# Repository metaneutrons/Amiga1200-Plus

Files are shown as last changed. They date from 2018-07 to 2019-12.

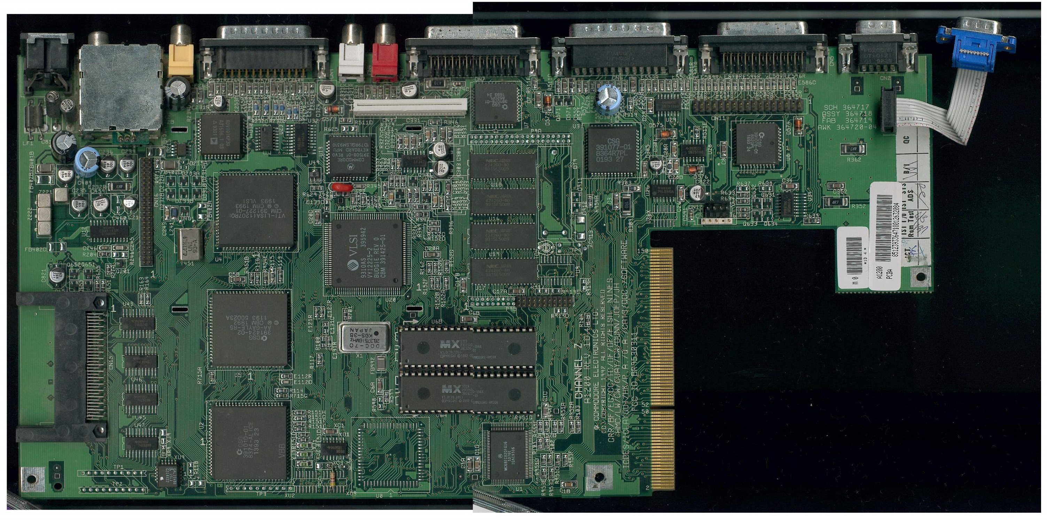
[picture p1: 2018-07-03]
a1200mb_rev1d4.jpg

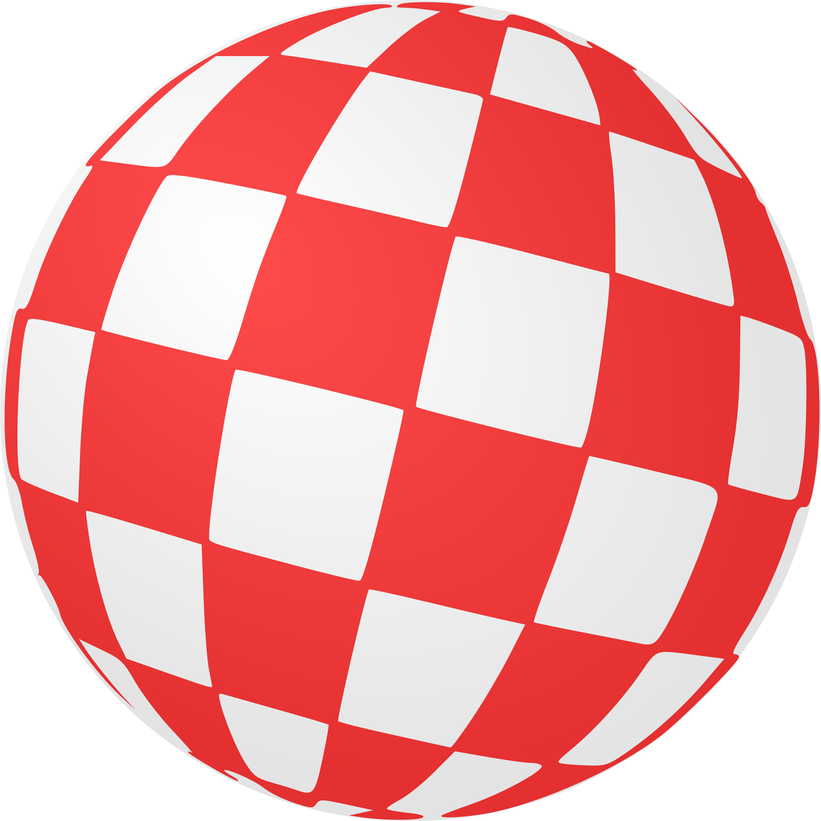
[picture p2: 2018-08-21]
Images/AmigaBall.png

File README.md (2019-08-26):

Scheme
# Amiga 1200+

## About

This project is a re-implementation of the Amiga 1200 board started from the schematics.
I made some changes and enhancements to the original schematics.

## Features

* All Original AA chips are needed and can be put into the sockets. These include Lisa, Paula, Alice and the two CIA chips.
* The CPU is removed, you need some accellerator board to run this board.
* The DRAM has been removed and the functionality has been moved to a daughterboard.
* Video output has been moved to a seperate output board. This board get all Lisa output signals and also all the typical Zorro signals. This means that an RTG card can be developed.
* The PCMCIA slot has been removed and in the free space a Compact Flash socket has been added.
* A 110V-240V AC-DC powersupply has been added, so no more power brick. This generates these voltages:
    * 5 Volts: main power rail 5 Amp capable
    * 12 Volts: 0.8 Amp capable
* two PC standard 3 Pin fan headers are added to the board.
* A non-volatile digipot has been added in the audio path, this allows you to set the stereo separation.
* Extension board connector for Mouse/Joystick/Network/FlashFloppy. (one is in development that has USB Mouse and two classic DB-9 connectors and autoswitches when fire button is pressed + ethernet)
* Replaced the keyboard controller by a modern MCU
* Dual ROM switcher
* DF0/DF1 Bootselector

## License


This project is licensed by a Creative Commons license; You are welcome (and encouraged!) to extend, re-spin and otherwise use and modify the design as allowed by the license. - see  [Creative Commons](https://creativecommons.org/licenses/by-sa/4.0/) for details

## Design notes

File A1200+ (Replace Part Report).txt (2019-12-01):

Replace Part Report
-------------------

Report Written : 6/10/2019 14:34:41
Design Path    : X:\Personal\Amiga1200Plus\A1200+.sch
Design Title   : A1200+
Created        : 26/06/2018 20:48:32
Last Saved     : 29/09/2019 12:27:12
Editing Time   : 21053 min

Replace Part:	6800pF/250V Ceramic 0805
Footprint:	<Any Footprint>

With Part:	3900pF/200V Ceramic 0805
Footprint:	<Default Footprint>

Replace matching components in the selection.

The following components were replaced:
---------------------------------------
C40
C30

                ---------------- End Of Report ----------------

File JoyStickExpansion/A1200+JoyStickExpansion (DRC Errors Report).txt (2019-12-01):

DRC Errors Report
-----------------

Report Written : 22/09/2019 14:22:56
Design Path    : X:\Personal\Amiga1200Plus\JoyStickExpansion\A1200+JoyStickExpansion.pcb
Design Title   : 
Created        : 9/06/2019 21:36:26
Last Saved     : 22/09/2019 14:22:43
Editing Time   : 2385 min

No errors found

The following rules were not checked:
    Spacing Rules:
        Testpoint
        Text
        Component
    All On Grid Rules
    Manufacturing Rules:
        Unreachable Testpoints
        Minimum Probe Points
        Split Plane Pad
        Bond Wire Length
        Wire Cross
        Wire Under Component
        Drill Backoff
        Minimum Pad Land
    Net Rules:
        Single Pin Nets
        Unfinished Track
        Track Layer
        Track Length
        Connection Length
        Connection Vias
        Pin Order
        Stub Via

All acceptance rules were checked.

No net class spacing rules defined.

No net class pair rules defined.

                ---------------- End Of Report ----------------

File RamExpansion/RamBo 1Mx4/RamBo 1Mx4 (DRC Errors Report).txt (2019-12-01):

DRC Errors Report
-----------------

Report Written : 19/09/2019 10:40:06
Design Path    : X:\Personal\Amiga1200Plus\RamExpansion\RamBo 1Mx4\RamBo 1Mx4.pcb
Design Title   : 
Created        : 8/06/2019 19:15:11
Last Saved     : 19/09/2019 10:40:02
Editing Time   : 418 min

No errors found

The following rules were not checked:
    Spacing Rules:
        Testpoint
        Text
        Component
    All On Grid Rules
    Manufacturing Rules:
        Unreachable Testpoints
        Minimum Probe Points
        Split Plane Pad
        Bond Wire Length
        Wire Cross
        Wire Under Component
        Drill Backoff
        Minimum Pad Land
    Net Rules:
        Single Pin Nets
        Unfinished Track
        Track Layer
        Track Length
        Connection Length
        Connection Vias
        Pin Order
        Stub Via

All acceptance rules were checked.

No net class spacing rules defined.

No net class pair rules defined.

                ---------------- End Of Report ----------------

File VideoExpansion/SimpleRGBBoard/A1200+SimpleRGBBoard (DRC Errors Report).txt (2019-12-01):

DRC Errors Report
-----------------

Report Written : 21/09/2019 11:47:59
Design Path    : X:\Personal\Amiga1200Plus\VideoExpansion\SimpleRGBBoard\A1200+SimpleRGBBoard.pcb
Design Title   : 
Created        : 5/06/2019 19:54:43
Last Saved     : 21/09/2019 11:47:56
Editing Time   : 632 min

No errors found

The following rules were not checked:
    Spacing Rules:
        Testpoint
        Text
        Component
    All On Grid Rules
    Manufacturing Rules:
        Unreachable Testpoints
        Minimum Probe Points
        Split Plane Pad
        Bond Wire Length
        Wire Cross
        Wire Under Component
        Drill Backoff
        Minimum Pad Land
    Net Rules:
        Single Pin Nets
        Unfinished Track
        Track Layer
        Track Length
        Connection Length
        Connection Vias
        Pin Order
        Stub Via

All acceptance rules were checked.

No net class spacing rules defined.

No net class pair rules defined.

                ---------------- End Of Report ----------------

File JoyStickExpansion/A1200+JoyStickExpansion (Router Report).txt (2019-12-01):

Router Report
-------------

Report Written : 22/09/2019 14:00:09
Design Path    : X:\Personal\Amiga1200Plus\JoyStickExpansion\A1200+JoyStickExpansion.pcb
Design Title   : 
Created        : 9/06/2019 21:36:26
Last Saved     : 22/09/2019 13:59:12
Editing Time   : 2362 min

Nets          =      173
Components    =       78
Connections   =      330
Vias          =      268
Routed Length =   2387.3 mm
Signal Layers =        4
Power Layers  =        0
Total Pins    =      597
Completion    =  100.00%
Unroutes      =        0
Routing Time  = 00:00:40

____________________________________________________________________________________________
|     |          |        |        |        |        |        |        |         |         |
|  #  |   Algo   | Shorts |DRC Errs|Failures|Unwired |  Vias  |  %Red  |  Time   |  Total  |
|_____|__________|________|________|________|________|________|________|_________|_________|
|    1| Bus      |       0|      66|       0|      21|     220|        |  0:00:00|  0:00:00|
|    2| Fanout   |       0|      67|       0|      21|     260|        |  0:00:01|  0:00:01|
|    3| Fanout   |       0|      66|       0|      21|     260|        |  0:00:00|  0:00:01|
|    4| Fanout   |       0|      66|       0|      21|     260|        |  0:00:00|  0:00:01|
|    5| Fanout   |       0|      66|       0|      21|     260|        |  0:00:01|  0:00:02|
|    6| Fanout   |       0|      66|       0|      21|     260|        |  0:00:00|  0:00:02|
|    7| Route    |       7|      66|       4|       0|     269|       0|  0:00:08|  0:00:10|
|    8| Route    |       0|      66|       5|       0|     271|       9|  0:00:03|  0:00:13|
|    9| Route    |       0|      66|       4|       0|     271|       0|  0:00:01|  0:00:14|
|   10| Route    |       0|      66|       4|       0|     269|       0|  0:00:00|  0:00:14|
|   11| Route    |       0|      66|       4|       0|     269|       0|  0:00:01|  0:00:15|
|   12| Route    |       0|      66|       4|       0|     269|       0|  0:00:00|  0:00:15|
|   13| Route    |       0|      66|       4|       0|     269|       0|  0:00:01|  0:00:16|
|   14| Route    |       0|      66|       4|       0|     269|       0|  0:00:00|  0:00:16|
|   15| Route    |       0|      66|       4|       0|     269|       0|  0:00:01|  0:00:17|
|   16| Route    |       0|      66|       4|       0|     269|       0|  0:00:00|  0:00:17|
|   17| Route    |       0|      66|       4|       0|     269|       0|  0:00:01|  0:00:18|
|   18| Route    |       0|      66|       4|       0|     269|       0|  0:00:00|  0:00:18|
|   19| Route    |       0|      66|       4|       0|     269|       0|  0:00:01|  0:00:19|
|   20| Route    |       0|      66|       4|       0|     269|       0|  0:00:00|  0:00:19|
|   21| Route    |       0|      66|       4|       0|     269|       0|  0:00:01|  0:00:20|
|   22| Route    |       0|      66|       4|       0|     269|       0|  0:00:00|  0:00:20|
|   23| Route    |       0|      66|       4|       0|     269|       0|  0:00:01|  0:00:21|
|   24| Route    |       0|      66|       4|       0|     269|       0|  0:00:00|  0:00:21|
|   25| Route    |       0|      66|       4|       0|     269|       0|  0:00:01|  0:00:22|
|   26| Route    |       0|      66|       4|       0|     269|       0|  0:00:00|  0:00:22|
|   27| Route    |       0|      66|       4|       0|     269|       0|  0:00:00|  0:00:22|
|   28| Route    |       0|      66|       4|       0|     269|       0|  0:00:00|  0:00:22|
|   29| Route    |       0|      66|       4|       0|     269|       0|  0:00:01|  0:00:23|
|   30| Route    |       0|      66|       4|       0|     269|       0|  0:00:00|  0:00:23|
|   31| Route    |       0|      66|       4|       0|     269|       0|  0:00:01|  0:00:24|
|   32| Filter   |       0|      66|       4|       0|     269|       0|  0:00:00|  0:00:24|
|   33| Filter   |       0|      66|       4|       0|     269|       0|  0:00:01|  0:00:25|
|   34| Filter   |       0|      66|       4|       0|     269|       0|  0:00:00|  0:00:25|
|   35| Filter   |       0|      66|       4|       0|     269|       0|  0:00:01|  0:00:26|
|   36| Filter   |       0|      66|       4|       0|     269|       0|  0:00:00|  0:00:26|
|   37| Clean    |       0|      66|      32|       0|     270|        |  0:00:03|  0:00:29|
|   38| Clean    |       0|      66|      31|       0|     268|        |  0:00:03|  0:00:32|
|   39| Clean    |       0|      66|      32|       0|     268|        |  0:00:02|  0:00:34|
|   40| Clean    |       0|      66|      31|       0|     268|        |  0:00:03|  0:00:37|
|   40| Recorner |       0|      66|       0|       0|     268|        |  0:00:01|  0:00:38|
|_____|__________|________|________|________|________|________|________|_________|_________|

                ---------------- End Of Report ----------------

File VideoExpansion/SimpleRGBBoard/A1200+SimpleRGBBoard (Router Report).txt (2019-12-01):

Router Report
-------------

Report Written : 19/09/2019 13:59:25
Design Path    : X:\Personal\Amiga1200Plus\VideoExpansion\SimpleRGBBoard\A1200+SimpleRGBBoard.pcb
Design Title   : 
Created        : 5/06/2019 19:54:43
Last Saved     : 19/09/2019 13:58:39
Editing Time   : 602 min

Nets          =      135
Components    =       35
Connections   =      142
Vias          =      133
Routed Length =   2826.1 mm
Signal Layers =        4
Power Layers  =        0
Total Pins    =      297
Completion    =  100.00%
Unroutes      =        0
Routing Time  = 00:00:24

____________________________________________________________________________________________
|     |          |        |        |        |        |        |        |         |         |
|  #  |   Algo   | Shorts |DRC Errs|Failures|Unwired |  Vias  |  %Red  |  Time   |  Total  |
|_____|__________|________|________|________|________|________|________|_________|_________|
|    1| Bus      |       0|       0|       0|      46|      70|        |  0:00:00|  0:00:00|
|    2| Fanout   |       0|       7|       2|      46|     149|        |  0:00:01|  0:00:01|
|    3| Fanout   |       1|       1|       2|      46|     149|        |  0:00:00|  0:00:01|
|    4| Fanout   |       1|       1|       2|      46|     149|        |  0:00:00|  0:00:01|
|    5| Fanout   |       1|       0|       2|      46|     149|        |  0:00:01|  0:00:02|
|    6| Fanout   |       0|       0|       3|      46|     148|        |  0:00:00|  0:00:02|
|    7| Route    |      47|      15|       0|       0|     127|       0|  0:00:01|  0:00:03|
|    8| Route    |      29|      17|       0|       0|     130|      25|  0:00:02|  0:00:05|
|    9| Route    |      18|       1|       0|       0|     124|      58|  0:00:01|  0:00:06|
|   10| Route    |       4|       6|       0|       0|     130|      47|  0:00:01|  0:00:07|
|   11| Route    |       0|       2|       0|       0|     136|      80|  0:00:01|  0:00:08|
|   12| Route    |       0|       8|       3|       0|     136|       0|  0:00:01|  0:00:09|
|   13| Route    |       2|      15|       1|       0|     136|       0|  0:00:01|  0:00:10|
|   14| Route    |       2|      15|       4|       0|     136|       0|  0:00:01|  0:00:11|
|   15| Route    |       2|       8|       1|       0|     136|      41|  0:00:00|  0:00:11|
|   16| Route    |       1|       2|       5|       0|     136|      70|  0:00:02|  0:00:13|
|   17| Route    |       0|       7|       1|       0|     136|       0|  0:00:01|  0:00:14|
|   18| Route    |       0|       8|       4|       0|     136|       0|  0:00:01|  0:00:15|
|   19| Route    |       1|       0|       0|       0|     136|      87|  0:00:00|  0:00:15|
|   20| Route    |       0|       0|       3|       0|     138|     100|  0:00:01|  0:00:16|
|   21| Filter   |       0|       0|       0|       0|     138|       0|  0:00:00|  0:00:16|
|   22| Clean    |       0|       0|      31|       0|     135|        |  0:00:02|  0:00:18|
|   23| Clean    |       0|       0|      31|       0|     133|        |  0:00:02|  0:00:20|
|   24| Clean    |       0|       0|      32|       0|     133|        |  0:00:02|  0:00:22|
|   25| Clean    |       0|       0|      31|       0|     133|        |  0:00:02|  0:00:24|
|   25| Recorner |       0|       0|       0|       0|     133|        |  0:00:00|  0:00:24|
|_____|__________|________|________|________|________|________|________|_________|_________|

                ---------------- End Of Report ----------------

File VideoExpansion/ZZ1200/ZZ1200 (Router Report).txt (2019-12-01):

Router Report
-------------

Report Written : 16/08/2019 20:23:38
Design Path    : \\Mac\repos\Personal\Amiga1200Plus\VideoExpansion\ZZ1200\ZZ1200.pcb
Design Title   : 
Created        : 5/06/2019 19:54:43
Last Saved     : 16/08/2019 20:23:16
Editing Time   : 688 min

Nets          =      130
Components    =       10
Connections   =       62
Vias          =       51
Routed Length =    924.9 mm
Signal Layers =        4
Power Layers  =        0
Total Pins    =      460
Completion    =  100.00%
Unroutes      =        0
Routing Time  = 00:00:06

____________________________________________________________________________________________
|     |          |        |        |        |        |        |        |         |         |
|  #  |   Algo   | Shorts |DRC Errs|Failures|Unwired |  Vias  |  %Red  |  Time   |  Total  |
|_____|__________|________|________|________|________|________|________|_________|_________|
|    1| Bus      |       0|       0|       0|      45|      17|        |  0:00:00|  0:00:00|
|    2| Fanout   |       0|       1|      23|      45|      60|        |  0:00:00|  0:00:00|
|    3| Fanout   |       0|       0|      23|      45|      60|        |  0:00:01|  0:00:01|
|    4| Fanout   |       0|       0|      23|      45|      60|        |  0:00:00|  0:00:01|
|    5| Fanout   |       0|       0|      23|      45|      60|        |  0:00:00|  0:00:01|
|    6| Fanout   |       0|       0|      23|      45|      60|        |  0:00:00|  0:00:01|
|    7| Route    |      10|       0|       0|       0|      53|       0|  0:00:01|  0:00:02|
|    8| Route    |       5|       0|       4|       0|      55|      50|  0:00:00|  0:00:02|
|    9| Route    |       0|       0|       0|       0|      57|     100|  0:00:01|  0:00:03|
|   10| Filter   |       0|       0|       0|       0|      57|       0|  0:00:00|  0:00:03|
|   11| Clean    |       0|       0|      12|       0|      51|        |  0:00:01|  0:00:04|
|   12| Clean    |       0|       0|      12|       0|      51|        |  0:00:00|  0:00:04|
|   13| Clean    |       0|       0|      12|       0|      51|        |  0:00:01|  0:00:05|
|   14| Clean    |       0|       0|      12|       0|      51|        |  0:00:01|  0:00:06|
|   14| Recorner |       0|       0|       0|       0|      51|        |  0:00:00|  0:00:06|
|_____|__________|________|________|________|________|________|________|_________|_________|

                ---------------- End Of Report ----------------

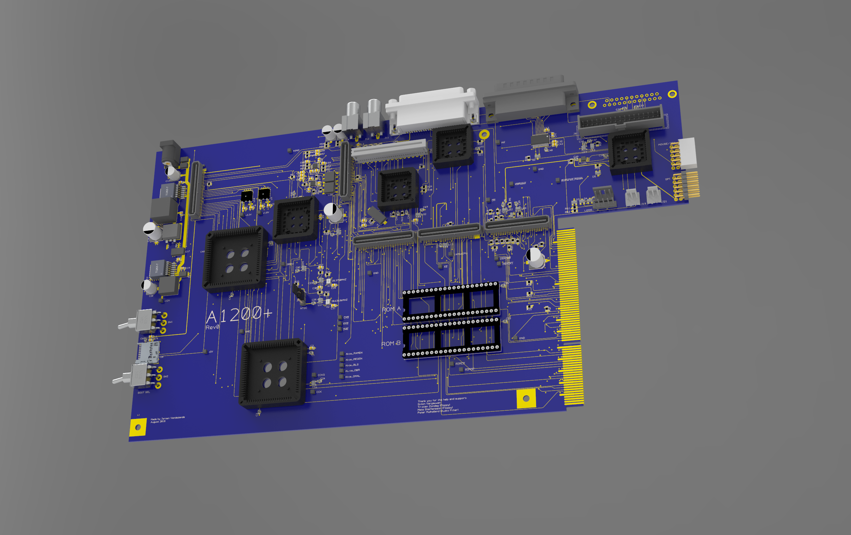
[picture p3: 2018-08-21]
Images/A1200+Render.png

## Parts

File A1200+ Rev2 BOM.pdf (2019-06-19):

### A1200+ (BOM Csv)

Count Count | Name | Value | Desc | Mfr | Part Number | Supplier | SPN | Footprint
14 | C[1-3],C5,C7,C[10-11],C26,C32,C36,C49,C58,C[60-61] | 100 nF | 3 Pin Capacitor | Murata | NFM21PC104R1E3D | | FN 1686518 | NFM21
15 | C4,C20,C[22-23],C[27-28],C33,C[37-39],C[44-47],C57 | 100nF/50V | 100nF/50V Ceramic Capacitor 0805 | MURATA | GCM21BR72A104KA37L | | FN 2470440 | 805
3 | C6,C52,C55 | 220µF/35V | Capacitor Alu Elec 220µF/35V | Panasonic | EEEFK1V221P | | FN 9695877 | Panasonic Cap Size F
1 | C8 | 1µF/50V | 1µF/50V Ceramic Capacitor 0805 | Murata | GRM21BR71H105KA12L | | FN 1735541RL | C0805
3 | C9,C16,C29 | 10µF/16V | 10µF/16V Ceramic Capacitor 0805 | Murata | GRM219R61C106KA73D | | FN 1845747 | C0805
3 | C12,C[34-35] | 220nF/50V | 220nF/50V Ceramic Capacitor 0805 | Murata | GRM21BR71H224KA01L | | FN 8820139RL | C0805
4 | C13,C17,C30,C40 | 6800pF/250V | Ceramic Capacitor 0805 | Kemet | C0805X682JAGACAUTO | Farnell | 2471761 | 805
3 | C14,C21,C50 | 100µF/35V | 100µF 35V Capacitor Hybrid Polymer | Panasonic | EEHZK1V101XP | Mouser | 667-EEH-ZK1V101XP | Panasonic Cap Size D8
2 | C15,C31 | 3900pF/200V | Ceramic Capacitor 0805 | Kemet | C0805C392J2GACAUTO | Farnell | 2426890 | 805
4 | C[18-19],C[24-25] | 100nF/50V | 100nF/50V Ceramic Capacitor 0805 | AVX | 08055C104KAZ2A | | FN 7569564 | C0805
6 | C41,C48,C51,C[53-54],C56 | 100nF | 3 Pin Capacitor | Murata | NFM21PC104R1E3D | | FN 1686518 | NFM21
2 | C[42-43] | 22pF/100V | 22pF/100V Ceramic Capacitor 0805 | AVX | 08051A220JAT2A | | FN 317500 | 805
1 | C59 | 470nF/25V | 470nF/25V Ceramic Capacitor 0805 | Kemet | C0805C474J3RACAUTO | | FN 2478263 | 805
1 | D1 | 30V / 200mA | Small Signal Schottky Diode | ON SEMICONDUCTOR | BAT54 | | FN 1467516 | SOT-23
1 | F1 | | 10A/250VAC Cartridge 5x20 Fuse Holder | WURTH ELEKTRONIK | 696105003002 | | FN 2471679 | 696105003002
1 | I1 | 10 mA | Constant Current Regulator | ON Semiconductor | NSI50010YT1GOSCT-ND | | | SOD-123
2 | J[1-2] | | RCA Connector PCB Black | CUI | RCJ-041 | Mouser | 490-RCJ-041 | RCJ-04x
1 | J3 | | DB-25 Female Right Angle | MultiComp | 8LCM025S-304B-XX | Farnell | 1099296 | DB25-FEMALE-RA
1 | J4 | | D-Sub Standard Connectors 25P MALE RIGHT ANGLE | NorComp | 182-025-113R531 | | MS 636-182-025-113R531 | DB25-MALE-RA
1 | J5 | | DB-23 Female Right Angle | | | | | DB23-FEMALE-RA
1 | J6 | | AC Power Entry Module | Qualtek | 770W-X2/10 | Mouser | 562-770W-X2/10 | 770W-X2/10
1 | J7 | | Box Header 34 Pins 2.54mm pitch | Harting | 09 18 534 7324 | Farnell | 1096992 | BOX-2x14
1 | J8 | | 31 Pin FPC connector 1.25mm Pitch | Molex | 39-53-2315 | Mouser | 538-39-53-2315 | 39-53-2315
2 | J9,J13 | | Board to Board & Mezzanine Connectors 40P 1.27 SMC Male R/A SMT Type | HARWIN | M55-7104042R | | 855-M55-7104042R | M55-7104042R
3 | J[10-12] | | FH-Board To Board Connector | TE Connectivity | 5146897-1 | Mouser | 571-5146897-1 | Free Height (FH) Plug 64
2 | J[14-15] | | Floppy Power Connector | TE CONNECTIVITY | 171825-4 | Farnell | 1654622 | 171825-4
2 | J[16-17] | | Wire-To-Board Connector, 2.54 mm, 3 Contacts, Header | Molex | 22-23-2031 | Farnell | 1462950 | FanHeader
1 | J18 | | 5 Pin SIL | AMP - TE CONNECTIVITY | 825433-5 | Farnell | 1187826 | 825433-5
1 | J19 | | Header Through Hole 22 position 2.00mm | | 57102-F08-11ULF | Digi-Key | 609-5095-ND | Header-22-2mm-TH
1 | J20 | | Compact Flash Socket | TE Connectivity | 1-1734451-1 | | | CompactFlashSocket
1 | J21 | | Header Through Hole 22 position 2.00mm | | 57102-F08-11ULF | Digi-Key | 609-5095-ND | Header-44-2mm-TH
1 | J22 | | Amiga 1200 Edge Connector | | | | | EdgeConnector_150_1.27mm
3 | JP[1-3] | | 3 Pin Jumper | | | | | Jumper_3_2.54
1 | L1 | 0.95 µH | chip ferrite bead | TE CONNECTIVITY | BMB2A0600BN3 | | FN 2329425 | 805
1 | PSU1 | 5V 30W | AC to DC power supply | Mean Well | IRM-30-5 | | 2815513 | IRM-30
2 | Q[1-2] | | MOSFET, N Channel, 2.7A, 60V | International Rectifier | IRLML0060TRPBF | | FN 1783927 | SOT-23
1 | Q3 | 7.1A / 12V | MOSFET Transistor, P Channel | Vishay | SI2333CDS-T1-GE3 | | FN 1779259 | SOT-23
3 | Q[4-6] | 60V 1.6A | MOSFET Transistor, P Channel | Vishay | SI2309CDS-T1-GE3 | | FN 1779264 | SOT-23
16 | R[1-3],R10,R17,R[21-22],R24,R30,R32,R[36-37],R40,R47,R63,R82 | 10K | Resistor Thick Film 0.1W 1% | | | | | R0805
11 | R4,R23,R29,R33,R35,R38,R55,R60,R64,R73,R85 | 1K | Resistor Thick Film 0.1W 1% | | | | | R0805
26 | R[5-9],R[11-16],R18,R[26-27],R[44-45],R48,R57,R62,R72,R[74-78],R81 | 4K7 | Resistor Thick Film 0.1W 1% | | | | | R0805
2 | R19,R25 | 360R | Resistor Thick Film 0.1W 1% | | | | | R0805
1

Count | Name | Value | Desc | Mfr | Part Number | Supplier | SPN | Footprint
1 | R20 | 10 | Resistor Thick Film 0.1W 1% | | | | | R0805
1 | R28 | 100 | Resistor Thick Film 0.1W 1% | | | | | R0805
5 | R31,R51,R54,R56,R59 | 68R | Resistor Thick Film 0.1W 1% | | | | | R0805
4 | R34,R39,R[42-43] | 330R | Resistor Thick Film 0.1W 1% | | | | | R0805
12 | R41,R[52-53],R[65-71],R[79-80] | 470 | Resistor Thick Film 0.1W 1% | | | | | R0805
1 | R46 | 1M | Resistor Thick Film 0.1W 1% | | | | | R0805
2 | R[49-50] | 200R | Resistor Thick Film 0.1W 1% | | | | | R0805
2 | R58,R61 | 470R | Resistor Thick Film 0.1W 1% | | | | | R0805
1 | R83 | 10R | Resistor Thick Film 0.1W 1% | | | | | R0805
4 | R84,R[88-89],R91 | 27R | Resistor Thick Film 0.1W 1% | | | | | R0805
3 | R[86-87],R90 | 100R | Resistor Thick Film 0.1W 1% | | | | | R0805
1 | SW1 | | Toggle Switch SPDT | Multicomp | 1MS1T2B4M7RE | Farnell | 9473297 | ToggleSwitchPCB_Vertical
7 | TP[1-7] | | Test Point | MultiComp | TEST-1(BK) | Farnell | 1702000 | TestPoint
3 | U[1-2],U14 | | Dual JFET-input Operational Amplifier | Texas Instruments | OPA1642AIDGKT | Farnell | 2323354 | MSOP8_MC
1 | U3 | | Schmitt-Trigger Inverter | ON SEMICONDUCTOR | M74VHC1GT14DTT1G | Farnell | 2534358 | SOT-23-5
6 | U[4-5],U18,U22,U25,U27 | | Single 2-input Positive-AND Gate | Texas Instruments | SN74LVC1G08DBVT | | FN 1236324 | SOT-23-5
1 | U6 | | Dual Non Volatile Digi-Pot | Analog Devices | AD5142ABRUZ10 | | 584-AD5142ABRUZ10 | TSSOP-20-B6.3-P0.65
2 | U7,U12 | | Amiga 8520 CIA | 3M | 8444-11B1-RK-TP | Farnell | 1183029 | PLCC-44
2 | U8,U10 | | Photo FET Optocoupler | On Semiconductor | H11F1SM | Farnell | 2825064 | H11F1SM
1 | U9 | | RS-232 Transceiver | Texas Instruments | SN65C3243DBR | Farnell | 2496635 | SSOP-28-P0.65-B5.3
1 | U11 | | Amiga Audio Chip | 3M | 8452-11B1-RK-TP | Farnell | 2673908 | PLCC-52
1 | U13 | | Amiga 1200 Keyboard Controller | 3M | 8444-11B1-RK-TP | Farnell | 1183029 | PLCC-44
1 | U15 | 4.0V | Power-On Reset | Texas Instruments | LP3470M5-4.00/NOPB | Farnell | 2492283 | SOT-23-5
1 | U16 | | Amiga 1200 GAL | | | | | PLCC-20-5X5-P50
1 | U17 | | Amiga Graphics Controller | 3M | 8484-11B1-RK-TP | Farnell | 1183033 | PLCC-84
1 | U19 | | Amiga 1200 Memory Controller | | | | | QFT-128_0.8
1 | U20 | | Amiga 1200 Gayle Chip | | | | | PLCC-84
2 | U21,U24 | | a 62408 rom in a DIL socket | Mill-Max Manufacturing Corp. 117-43-642-41-005000 | | Digi-Key | ED90229-ND | DIP Socket 42
1 | U23 | 12V | DC-DC Convertor 12V 10W | Meanwell | SKM10E-12 | Digikey | 1866-4632-ND | SKM10E
1 | U26 | | Amiga DMA Controller | 3M | 8484-11B1-RK-TP | Farnell | 1183033 | PLCC-84
1 | X1 | 3MHZ | Crystal HC49 SMD | Abracon LLC | ABLS-LR-3.000MHZ-T | Digi-Key | 535-10158-1-ND | HC49
1 | X2 | | | | | | | OscSocket

2

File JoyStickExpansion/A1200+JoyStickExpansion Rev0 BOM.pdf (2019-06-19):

### A1200+JoyStickExpansion (BOM Csv)

Count | Name | Value | Desc | Mfr | Part Number | Supplier | SPN | Footprint
4 | C[1-2],C28,C31 | 100nF/50V | 100nF/50V Ceramic Capacitor 0805 | AVX | 08055C104KAZ2A | | FN 7569564 | C0805
20 | C3,C[6-14],C[18-23],C[25-27],C29 | 100 nF | 3 Pin Capacitor | Murata | NFM21PC104R1E3D | | FN 1686518 | NFM21
3 | C[4-5],C24 | 10µF/16V | 10µF/16V Ceramic Capacitor 0805 | Murata | GRM219R61C106KA73D | | FN 1845747 | C0805
3 | C[15-17] | 4.7µF/100V | 4.7µF/100V Ceramic Capacitor 0805 | AVX | 12061Z475KAT2A | | FN 2310265 | C1206
1 | C30 | 1µF/50V | 1µF/50V Ceramic Capacitor 0805 | Murata | GRM21BR71H105KA12L | | FN 1735541RL | C0805
3 | D[1-3] | | Green Red 0805 | KINGBRIGHT | KP-2012MGC | | 8529906 | 0805LED
3 | I[1-3] | 10 mA | Constant Current Regulator | ON Semiconductor | NSI50010YT1GOSCT-ND | | | SOD-123
2 | J[1-2] | | Board to Board & Mezzanine Connectors 40P 1.27 SMC Female R/A SMT Type | HARWIN | M55-6104042R | | 855-M55-6104042R | M55-6104042R
1 | J3 | | 4 Pin Connector | JST | B4B-PH-SM4-TB(LF)(SN) | | FN 9491929 | PH4
2 | J[4-5] | | DE-09 Male Right Angle Connector | NorComp | 682-009-113R531 | Mouser | 636-682-009-113R531 | DE-09 Male Right Angle
1 | J6 | | 10/100BaseT RJ45 LAN Connector with integrated transformer | WURTH ELEKTRONIK | 74990111217 | | FN 2356118 | 74990111217
1 | J7 | | USB Connector Type A | WURTH ELEKTRONIK | 61400416021 | Farnell | 1642033 | USB Type A
1 | J8 | | Programming header for AVR MCUs | | | | | TC2030
1 | J9 | | 8 Pin SIL | AMP - TE CONNECTIVITY | 825433-8 | Farnell | 1187828 | SIL-8-2.54
2 | L[1-2] | 0.95 µH | chip ferrite bead | TE CONNECTIVITY | BMB2A0600BN3 | | FN 2329425 | 805
1 | Q1 | 30V, 5A | MOSFET, N Channel, 5A, 30V | Infineon | IRLML6344TRPBF | Farnell | 1857299 | SOT-23
3 | R[1-2],R7 | 4K7 | Resistor Thick Film 0.1W 1% | | | | | R0805
4 | R[3-6] | 49R9 | Resistor Thick Film 0.1W 1% | | | | | R0805
1 | R8 | 3K01 | Resistor Thick Film 0.1W 1% | | | | | R0805
2 | R[9-10] | 220R | Resistor Thick Film 0.1W 1% | | | | | R0805
2 | R[11-12] | 22R | Resistor Thick Film 0.1W 1% | | | | | R0805
1 | R13 | 10K | Resistor Thick Film 0.1W 1% | | | | | R0805
1 | R14 | 47R | Resistor Thick Film 0.1W 1% | | | | | R0805
1 | SW1 | | Toggle Switch SPDT | Multicomp | 1MS1T2B4M7RE | Farnell | 9473297 | ToggleSwitchPCB_Vertical
1 | U1 | | I2C Controller for parallel bus | NXP | PCF8584T/2,512 | | 2400586 | SOIC-20W
1 | U2 | 3.3V 250 mA | LDO Linear Voltage Regulator | Microchip | MCP1702T-3302E/CB | | FN 1331490 | SOT-23A
1 | U3 | | Ethernet Controller 100 Mbps | Microchip | KSZ8851-16MLL | Farnell | 2991829 | TQFP-48-0.5
2 | U[4-5] | | Single OR Gate | Texas Instruments | SN74LVC1G32DBVR | | FN 1287525 | SOT-23-5
3 | U[6-8] | | 8-bit dual supply Translating Transceiver with 3-state outputs | Nexperia | 74LVC8T245PW,118 | Farnell | 2444917 | TSSOP-24
1 | U9 | | 8-bit Atmel Microcontroller with USB | Microchip | AT90USB1287-AU | Farnell | 1748496 | TQFP-64
1 | U10 | | REGISTER | Nexperia | 74HC166D-Q100J | Farnell | 2777725 | SOIC16
1 | X1 | 25 MHZ | Crystal Oscillator | Epson | X1G0041710033 SG-210STF 25 MHZ L | | FN 2405724 | EPSON SG210
1 | X2 | 16 MHZ | Crystal Oscillator | Epson | 1G0041710027 SG-210STF 16 MHZ L | Farnell | 2405718 | EPSON SG210

1

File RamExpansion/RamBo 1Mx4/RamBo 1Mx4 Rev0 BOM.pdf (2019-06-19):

### RamBo 1Mx4 (BOM Csv)

Count | Name | Value | Desc | Mfr | Part Number | Supplier | SPN | Footprint
8 | C[1-8] | 100nF | 3 Pin Capacitor | Murata | NFM21PC104R1E3D | | FN 1686518 | NFM21
1 | C9 | 10µF/16V | 10µF/16V Ceramic Capacitor 0805 | Murata | GRM219R61C106KA73D | | FN 1845747 | C0805
1 | J1 | | FH-Board To Board Connector Receptacle | TE Connectivity | 5120523-1 | Mouser | 571-5120523-1 | Free Height (FH) Receptacle 64
1 | R1 | 470R | Resistor Thick Film 0.1W 1% | | | | | R0805
8 | U[1-8] | | CMOS DRAM 1Mx4 | | | | | SOJ20_RAM

1

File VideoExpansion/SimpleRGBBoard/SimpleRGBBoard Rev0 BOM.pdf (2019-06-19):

### A1200+SimpleRGBBoard (BOM Csv)

Count | Name | Value | Desc | Mfr | Part Number | Supplier | SPN | Footprint
4 | C1,C5,C[8-9] | 100nF/50V | 100nF/50V Ceramic Capacitor 0805 | MURATA | GCM21BR72A104KA37L | | FN 2470440 | 805
2 | C2,C6 | 10µF/16V | 10µF/16V Ceramic Capacitor 0805 | Murata | GRM219R61C106KA73D | | FN 1845747 | C0805
3 | C[3-4],C7 | 100nF | 3 Pin Capacitor | Murata | NFM21PC104R1E3D | | FN 1686518 | NFM21
3 | C[10-11],C14 | 10nF/50V | 10nF/50V Ceramic Capacitor 0805 | AVX | 08055C103KAT2A | | FN 499225 | 805
1 | C12 | 1µF/50V | 1µF/50V Ceramic Capacitor 0805 | Murata | GRM21BR71H105KA12L | | FN 1735541RL | C0805
1 | C13 | 100nF/50V | 100nF/50V Ceramic Capacitor 0805 | AVX | 08055C104KAZ2A | | FN 7569564 | C0805
2 | J[1-2] | | FH-Board To Board Connector Receptacle | TE Connectivity | 5120523-1 | Mouser | 571-5120523-1 | Free Height (FH) Receptacle 64
1 | J3 | | D Sub Connector, Right Angle, HD26, 26 Contacts, Plug, Through Hole, DA, Steel Body | Harting | 9562627813 | Farnell | 2752096 | DB-26 RA Male
1 | L1 | 0.95 µH | chip ferrite bead | TE CONNECTIVITY | BMB2A0600BN3 | | FN 2329425 | 805
5 | R[1-2],R[4-6] | 75 | Resistor Thick Film 0.1W 1% | | | | | R0805
1 | R3 | 360 | Resistor Thick Film 0.1W 1% | | | | | R0805
1 | R7 | 68 | Resistor Thick Film 0.1W 1% | | | | | R0805
1 | R8 | 1K | Resistor Thick Film 0.1W 1% | | | | | R0805
1 | R9 | 530R | Resistor Thick Film 0.1W 1% | | | | | R0805
1 | U1 | | Triple 8-Bit High Speed Video DAC | Analog Devices | ADV7125JSTZ240 | Farnell | 1438733 | TQFP-48-0.5
1 | U2 | | 8-bit dual supply Translating Transceiver with 3-state outputs | Nexperia | 74LVC8T245PW,118 | Farnell | 2444917 | TSSOP-24
1 | U3 | 1.235V | Voltage reference | Texas Instruments | LM385M3-1.2 | Farnell | 9778152 | SOT-23

1

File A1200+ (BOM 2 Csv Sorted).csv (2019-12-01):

Name | Value | Desc | Mfr | Part Number | Footprint
C9 | 1µF/50V | 1µF/50V Ceramic Capacitor 0805 | Murata | GRM21BR71H105KA12L | C0805
C63 | 1µF/50V | 1µF/50V Ceramic Capacitor 0805 | Murata | GRM21BR71H105KA12L | C0805
C64 | 1µF/50V | 1µF/50V Ceramic Capacitor 0805 | Murata | GRM21BR71H105KA12L | C0805
C1 | 10µF/16V | 10µF/16V Ceramic Capacitor 0805 | Murata | GRM219R61C106KA73D | C0805
C8 | 10µF/16V | 10µF/16V Ceramic Capacitor 0805 | Murata | GRM219R61C106KA73D | C0805
C16 | 10µF/16V | 10µF/16V Ceramic Capacitor 0805 | Murata | GRM219R61C106KA73D | C0805
C43 | 10µF/16V | 10µF/16V Ceramic Capacitor 0805 | Murata | GRM219R61C106KA73D | C0805
C49 | 10µF/16V | 10µF/16V Ceramic Capacitor 0805 | Murata | GRM219R61C106KA73D | C0805
C6 | 10nF/50V | 10nF/50V Ceramic Capacitor 0805 | AVX | 08055C103KAT2A | 0805
C14 | 100µF/35V | 100µF 35V Capacitor Hybrid Polymer | Panasonic | EEHZK1V101XP | Panasonic Cap Size D8
C21 | 100µF/35V | 100µF 35V Capacitor Hybrid Polymer | Panasonic | EEHZK1V101XP | Panasonic Cap Size D8
C5 | 100 nF | 3 Pin Capacitor | Murata | NFM21PC104R1E3D | NFM21
C7 | 100 nF | 3 Pin Capacitor | Murata | NFM21PC104R1E3D | NFM21
C10 | 100 nF | 3 Pin Capacitor | Murata | NFM21PC104R1E3D | NFM21
C26 | 100 nF | 3 Pin Capacitor | Murata | NFM21PC104R1E3D | NFM21
C27 | 100 nF | 3 Pin Capacitor | Murata | NFM21PC104R1E3D | NFM21
C28 | 100 nF | 3 Pin Capacitor | Murata | NFM21PC104R1E3D | NFM21
C32 | 100 nF | 3 Pin Capacitor | Murata | NFM21PC104R1E3D | NFM21
C36 | 100 nF | 3 Pin Capacitor | Murata | NFM21PC104R1E3D | NFM21
C41 | 100 nF | 3 Pin Capacitor | Murata | NFM21PC104R1E3D | NFM21
C51 | 100 nF | 3 Pin Capacitor | Murata | NFM21PC104R1E3D | NFM21
C54 | 100 nF | 3 Pin Capacitor | Murata | NFM21PC104R1E3D | NFM21
C62 | 100 nF | 3 Pin Capacitor | Murata | NFM21PC104R1E3D | NFM21
C66 | 100 nF | 3 Pin Capacitor | Murata | NFM21PC104R1E3D | NFM21
C67 | 100 nF | 3 Pin Capacitor | Murata | NFM21PC104R1E3D | NFM21
C50 | 100nF | 3 Pin Capacitor | Murata | NFM21PC104R1E3D | NFM21
C53 | 100nF | 3 Pin Capacitor | Murata | NFM21PC104R1E3D | NFM21
C55 | 100nF | 3 Pin Capacitor | Murata | NFM21PC104R1E3D | NFM21
C58 | 100nF | 3 Pin Capacitor | Murata | NFM21PC104R1E3D | NFM21
C59 | 100nF | 3 Pin Capacitor | Murata | NFM21PC104R1E3D | NFM21
C60 | 100nF | 3 Pin Capacitor | Murata | NFM21PC104R1E3D | NFM21
C11 | 100nF/50V | 100nF/50V Ceramic Capacitor 0805 | MURATA | GCM21BR72A104KA37L | 0805
C18 | 100nF/50V | 100nF/50V Ceramic Capacitor 0805 | AVX | 08055C104KAZ2A | C0805
C19 | 100nF/50V | 100nF/50V Ceramic Capacitor 0805 | AVX | 08055C104KAZ2A | C0805
C24 | 100nF/50V | 100nF/50V Ceramic Capacitor 0805 | AVX | 08055C104KAZ2A | C0805
C25 | 100nF/50V | 100nF/50V Ceramic Capacitor 0805 | AVX | 08055C104KAZ2A | C0805
C46 | 100nF/50V | 100nF/50V Ceramic Capacitor 0805 | MURATA | GCM21BR72A104KA37L | 0805
C47 | 100nF/50V | 100nF/50V Ceramic Capacitor 0805 | MURATA | GCM21BR72A104KA37L | 0805
C2 | 220nF/50V | 220nF/50V Ceramic Capacitor 0805 | Murata | GRM21BR71H224KA01L | C0805
C3 | 220nF/50V | 220nF/50V Ceramic Capacitor 0805 | Murata | GRM21BR71H224KA01L | C0805
C4 | 220nF/50V | 220nF/50V Ceramic Capacitor 0805 | Murata | GRM21BR71H224KA01L | C0805
C12 | 220nF/50V | 220nF/50V Ceramic Capacitor 0805 | Murata | GRM21BR71H224KA01L | C0805
C20 | 220nF/50V | 220nF/50V Ceramic Capacitor 0805 | Murata | GRM21BR71H224KA01L | C0805
C22 | 220nF/50V | 220nF/50V Ceramic Capacitor 0805 | Murata | GRM21BR71H224KA01L | C0805
C23 | 220nF/50V | 220nF/50V Ceramic Capacitor 0805 | Murata | GRM21BR71H224KA01L | C0805
C29 | 220nF/50V | 220nF/50V Ceramic Capacitor 0805 | Murata | GRM21BR71H224KA01L | C0805
C33 | 220nF/50V | 220nF/50V Ceramic Capacitor 0805 | Murata | GRM21BR71H224KA01L | C0805
C34 | 220nF/50V | 220nF/50V Ceramic Capacitor 0805 | Murata | GRM21BR71H224KA01L | C0805
C37 | 220nF/50V | 220nF/50V Ceramic Capacitor 0805 | Murata | GRM21BR71H224KA01L | C0805
C38 | 220nF/50V | 220nF/50V Ceramic Capacitor 0805 | Murata | GRM21BR71H224KA01L | C0805
C39 | 220nF/50V | 220nF/50V Ceramic Capacitor 0805 | Murata | GRM21BR71H224KA01L | C0805
C44 | 220nF/50V | 220nF/50V Ceramic Capacitor 0805 | Murata | GRM21BR71H224KA01L | C0805
C45 | 220nF/50V | 220nF/50V Ceramic Capacitor 0805 | Murata | GRM21BR71H224KA01L | C0805
C48 | 220nF/50V | 220nF/50V Ceramic Capacitor 0805 | Murata | GRM21BR71H224KA01L | C0805
C57 | 220nF/50V | 220nF/50V Ceramic Capacitor 0805 | Murata | GRM21BR71H224KA01L | C0805
C65 | 330nF/50V | 470nF/25V Ceramic Capacitor 0805 | AVX | 08055C334KAT2A | 0805
C42 | 470µF/16V | 470µF 16V Capacitor Poly Alu Elec | WURTH ELEKTRONIK | 875075361005 | CAP_SMD_ELEC_10mm
C35 | 1000µF/16V | 1000µF 16V Capacitor Poly Alu Elec | Panasonic | 16SEF1000M | PanasonicSizeF13
C52 | 1000µF/16V | 1000µF 16V Capacitor Poly Alu Elec | Panasonic | 16SEF1000M | PanasonicSizeF13
C56 | 1000µF/16V | 1000µF 16V Capacitor Poly Alu Elec | Panasonic | 16SEF1000M | PanasonicSizeF13
C61 | 1000µF/16V | 1000µF 16V Capacitor Poly Alu Elec | Panasonic | 16SEF1000M | PanasonicSizeF13
C15 | 3900pF/200V | Ceramic Capacitor 0805 | Kemet | C0805C392J2GACAUTO | 0805
C31 | 3900pF/200V | Ceramic Capacitor 0805 | Kemet | C0805C392J2GACAUTO | 0805
C30 | 6800pF | Ceramic Capacitor 0805 | Kemet | C0805X682JAGACAUTO | 0805
C40 | 6800pF | Ceramic Capacitor 0805 | Kemet | C0805X682JAGACAUTO | 0805
C13 | 6800pF/250V | Ceramic Capacitor 0805 | Kemet | C0805X682JAGACAUTO | 0805
C17 | 6800pF/250V | Ceramic Capacitor 0805 | Kemet | C0805X682JAGACAUTO | 0805
D10 |  | Green Red 0805 | KINGBRIGHT | KP-2012MGC | 0805LED
D11 |  | Green Red 0805 | KINGBRIGHT | KP-2012MGC | 0805LED
D1 | 5V | 4 Channel TVS Diodes | Wurth Elektronik | 82402374 | SC70-5
D2 | 5V | 4 Channel TVS Diodes | Wurth Elektronik | 82402374 | SC70-5
D3 | 5V | 4 Channel TVS Diodes | Wurth Elektronik | 82402374 | SC70-5
D4 | 5V | 4 Channel TVS Diodes | Wurth Elektronik | 82402374 | SC70-5
D5 | 5V | 4 Channel TVS Diodes | Wurth Elektronik | 82402374 | SC70-5
D6 | 5V | 4 Channel TVS Diodes | Wurth Elektronik | 82402374 | SC70-5
D7 | 5V | 4 Channel TVS Diodes | Wurth Elektronik | 82402374 | SC70-5
D8 | 5V | 4 Channel TVS Diodes | Wurth Elektronik | 82402374 | SC70-5
D9 | 30V / 200mA | Small Signal Schottky Diode | ON SEMICONDUCTOR | BAT54 | SOT-23
F1 |  | 10A/250VAC Cartridge 5x20 Fuse Holder | WURTH ELEKTRONIK | 696105003002 | 696105003002
I1 | 10 mA | Constant Current Regulator | ON Semiconductor | NSI50010YT1GOSCT-ND | SOD-123
I2 | 10 mA | Constant Current Regulator | ON Semiconductor | NSI50010YT1GOSCT-ND | SOD-123
I3 | 10 mA | Constant Current Regulator | ON Semiconductor | NSI50010YT1GOSCT-ND | SOD-123
J1 |  | RCA Connector PCB Black | CUI | RCJ-041 | RCJ-04x
J2 |  | RCA Connector PCB Black | CUI | RCJ-041 | RCJ-04x
J3 |  | DB-25 Female Right Angle | MultiComp | 8LCM025S-304B-XX | DB25-FEMALE-RA
J4 |  | D-Sub Standard Connectors 25P MALE RIGHT ANGLE | NorComp | 182-025-113R531 | DB25-MALE-RA
J5 |  | DB-23 Female Right Angle |  |  | DB23-FEMALE-RA
J6 |  | AC Power Entry Module | Qualtek | 770W-X2/10 | 770W-X2/10
J7 |  | Box Header 34 Pins 2.54mm pitch | Harting | 09 18 534 7324 | BOX-2x14
J8 |  | 31 Pin FPC connector 1.25mm Pitch | Molex | 39-53-2315 | 39-53-2315
J9 |  | Board to Board & Mezzanine Connectors 40P 1.27 SMC Male R/A SMT Type | HARWIN | M55-7104042R | M55-7104042R
J10 |  | FH-Board To Board Connector | TE Connectivity | 5146897-1 | Free Height (FH) Plug 64
J11 |  | FH-Board To Board Connector | TE Connectivity | 5146897-1 | Free Height (FH) Plug 64
J12 |  | FH-Board To Board Connector | TE Connectivity | 5146897-1 | Free Height (FH) Plug 64
J13 |  | Programming header for AVR MCUs |  |  | TC2030
J14 |  | Board to Board & Mezzanine Connectors 40P 1.27 SMC Male R/A SMT Type | HARWIN | M55-7104042R | M55-7104042R
J15 |  | Floppy Power Connector | TE CONNECTIVITY | 171825-4 | 171825-4
J16 |  | Floppy Power Connector | TE CONNECTIVITY | 171825-4 | 171825-4
J17 |  | Wire-To-Board Connector, 2.54 mm, 3 Contacts, Header | Molex | 22-23-2031 | FanHeader
J18 |  | Wire-To-Board Connector, 2.54 mm, 3 Contacts, Header | Molex | 22-23-2031 | FanHeader
J19 |  | 5 Pin SIL | AMP - TE CONNECTIVITY | 825433-5 | 825433-5
J20 |  | 4 Pin Connector | JST | B4B-PH-SM4-TB(LF)(SN) | PH4
J21 |  | Header Through Hole 22 position 2.00mm |  | 57102-F08-11ULF | Header-22-2mm-TH
J22 |  | Compact Flash Socket | TE Connectivity | 1-1734451-1 | CompactFlashSocket
J23 |  | Header Through Hole 22 position 2.00mm |  | 57102-F08-11ULF | Header-44-2mm-TH
J24 |  | Amiga 1200 Edge Connector |  |  | EdgeConnector_150_1.27mm
JP1 |  | 3 Pin Jumper |  |  | Jumper_3_2.54
JP2 |  | 3 Pin Jumper |  |  | Jumper_3_2.54
JP3 |  | 3 Pin Jumper |  |  | Jumper_3_2.54
JP4 |  | 3 Pin Jumper |  |  | Jumper_3_2.54
L1 | 0.95 µH | chip ferrite bead | TE CONNECTIVITY | BMB2A0600BN3 | 0805
L2 | 0.95 µH | chip ferrite bead | TE CONNECTIVITY | BMB2A0600BN3 | 0805
L3 | 0.95 µH | chip ferrite bead | TE CONNECTIVITY | BMB2A0600BN3 | 0805
PSU1 | 5V 30W | AC to DC power supply | Mean Well | IRM-30-5 | IRM-30
Q1 |  | MOSFET, N Channel, 2.7A, 60V | International Rectifier | IRLML0060TRPBF | SOT-23
Q2 |  | MOSFET, N Channel, 2.7A, 60V | International Rectifier | IRLML0060TRPBF | SOT-23
Q7 |  | MOSFET, N Channel, 2.7A, 60V | International Rectifier | IRLML0060TRPBF | SOT-23
Q8 |  | MOSFET, N Channel, 2.7A, 60V | International Rectifier | IRLML0060TRPBF | SOT-23
Q9 |  | MOSFET, N Channel, 2.7A, 60V | International Rectifier | IRLML0060TRPBF | SOT-23
Q11 |  | MOSFET, N Channel, 2.7A, 60V | International Rectifier | IRLML0060TRPBF | SOT-23
Q3 | 60V 1.6A | MOSFET Transistor, P Channel | Vishay | SI2309CDS-T1-GE3 | SOT-23
Q4 | 60V 1.6A | MOSFET Transistor, P Channel | Vishay | SI2309CDS-T1-GE3 | SOT-23
Q5 | 60V 1.6A | MOSFET Transistor, P Channel | Vishay | SI2309CDS-T1-GE3 | SOT-23
Q10 | 60V 100A | MOSFET Transistor, P Channel | Infineon | SI2309CDS-T1-GE3 | TO263-3 Lead
R9 | 1K | Resistor Thick Film 0.1W 1% |  |  | R0805
R10 | 1K | Resistor Thick Film 0.1W 1% |  |  | R0805
R11 | 1K | Resistor Thick Film 0.1W 1% |  |  | R0805
R14 | 1K | Resistor Thick Film 0.1W 1% |  |  | R0805
R18 | 1K | Resistor Thick Film 0.1W 1% |  |  | R0805
R19 | 1K | Resistor Thick Film 0.1W 1% |  |  | R0805
R40 | 1K | Resistor Network | Bourns | CAY17-102JALF | YC158
R46 | 1K | Resistor Thick Film 0.1W 1% |  |  | R0805
R55 | 1K | Resistor Thick Film 0.1W 1% |  |  | R0805
R8 | 1K69 | Resistor Thick Film 0.1W 1% |  |  | R0805
R13 | 1K69 | Resistor Thick Film 0.1W 1% |  |  | R0805
R26 | 1R | Resistor Thick Film 0.1W 1% |  |  | R0805
R5 | 4K7 | Resistor Thick Film 0.1W 1% |  |  | R0805
R21 | 4K7 | Resistor Thick Film 0.1W 1% |  |  | R0805
R27 | 4K7 | Resistor Thick Film 0.1W 1% |  |  | R0805
R30 | 4K7 | Resistor Thick Film 0.1W 1% |  |  | R0805
R34 | 4K7 | Resistor Thick Film 0.1W 1% |  |  | R0805
R35 | 4K7 | Resistor Thick Film 0.1W 1% |  |  | R0805
R37 | 4K7 | Resistor Thick Film 0.1W 1% |  |  | R0805
R39 | 4K7 | Resistor Thick Film 0.1W 1% |  |  | R0805
R49 | 4K7 | Resistor Thick Film 0.1W 1% |  |  | R0805
R50 | 4K7 | Resistor Thick Film 0.1W 1% |  |  | R0805
R53 | 4K7 | Resistor Network | Bourns | CAY17-472JALF | YC158
R54 | 4K7 | Resistor Thick Film 0.1W 1% |  |  | R0805
R58 | 4K7 | Resistor Thick Film 0.1W 1% |  |  | R0805
R66 | 4K7 | Resistor Thick Film 0.1W 1% |  |  | R0805
R67 | 4K7 | Resistor Thick Film 0.1W 1% |  |  | R0805
R1 | 10K | Resistor Thick Film 0.1W 1% |  |  | R0805
R2 | 10K | Resistor Thick Film 0.1W 1% |  |  | R0805
R3 | 10K | Resistor Thick Film 0.1W 1% |  |  | R0805
R4 | 10K | Resistor Thick Film 0.1W 1% |  |  | R0805
R6 | 10K | Resistor Thick Film 0.1W 1% |  |  | R0805
R7 | 10K | Resistor Thick Film 0.1W 1% |  |  | R0805
R15 | 10K | Resistor Thick Film 0.1W 1% |  |  | R0805
R16 | 10K | Resistor Thick Film 0.1W 1% |  |  | R0805
R17 | 10K | Resistor Thick Film 0.1W 1% |  |  | R0805
R22 | 10K | Resistor Thick Film 0.1W 1% |  |  | R0805
R24 | 10K | Resistor Thick Film 0.1W 1% |  |  | R0805
R48 | 10K | Resistor Thick Film 0.1W 1% |  |  | R0805
R51 | 10K | Resistor Thick Film 0.1W 1% |  |  | R0805
R56 | 10K | Resistor Thick Film 0.1W 1% |  |  | R0805
R59 | 10K | Resistor Thick Film 0.1W 1% |  |  | R0805
R31 | 10R | Resistor Thick Film 0.1W 1% |  |  | R0805
R28 | 27R | Resistor Thick Film 0.1W 1% |  |  | R0805
R29 | 27R | Resistor Thick Film 0.1W 1% |  |  | R0805
R60 | 27R | Resistor Thick Film 0.1W 1% |  |  | R0805
R61 | 27R | Resistor Thick Film 0.1W 1% |  |  | R0805
R62 | 27R | Resistor Thick Film 0.1W 1% |  |  | R0805
R63 | 27R | Resistor Thick Film 0.1W 1% |  |  | R0805
R64 | 27R | Resistor Thick Film 0.1W 1% |  |  | R0805
R20 | 68R | Resistor Thick Film 0.1W 1% |  |  | R0805
R41 | 68R | Resistor Thick Film 0.1W 1% |  |  | R0805
R42 | 68R | Resistor Thick Film 0.1W 1% |  |  | R0805
R45 | 68R | Resistor Thick Film 0.1W 1% |  |  | R0805
R57 | 68R | Resistor Thick Film 0.1W 1% |  |  | R0805
R38 | 100K | Resistor Thick Film 0.1W 1% |  |  | R0805
R12 | 100R | Resistor Thick Film 0.1W 1% |  |  | R0805
R32 | 200R | Resistor Thick Film 0.1W 1% |  |  | R0805
R33 | 200R | Resistor Thick Film 0.1W 1% |  |  | R0805
R23 | 220R | Resistor Thick Film 0.1W 1% |  |  | R0805
R25 | 220R | Resistor Thick Film 0.1W 1% |  |  | R0805
R43 | 470R | Resistor Thick Film 0.1W 1% |  |  | R0805
R44 | 470R | Resistor Network | Bourns | CAY17-471JALF | YC158
R47 | 470R | Resistor Thick Film 0.1W 1% |  |  | R0805
R52 | 470R | Resistor Network | Bourns | CAY17-471JALF | YC158
R65 | 470R | Resistor Thick Film 0.1W 1% |  |  | R0805
SW1 |  | Toggle Switch SPDT | Multicomp | 1MS1T2B4M7RE | ToggleSwitchPCB_Vertical
U1 |  | Dual JFET-input Operational Amplifier | Texas Instruments | OPA1642AIDGKT | MSOP8_MC
U2 |  | Dual JFET-input Operational Amplifier | Texas Instruments | OPA1642AIDGKT | MSOP8_MC
U3 |  | Schmitt-Trigger Inverter | ON SEMICONDUCTOR | M74VHC1GT14DTT1G | SOT-23-5
U4 |  | Single 2-input Positive-AND Gate | Texas Instruments | SN74LVC1G08DBVT | SOT-23-5
U5 |  | Dual Non Volatile Digi-Pot | Analog Devices | AD5142ABRUZ10 | TSSOP-16-B4.4-P0.65
U6 |  | Amiga 8520 CIA | 3M | 8444-11B1-RK-TP | PLCC-44
U7 |  | Photo FET Optocoupler | On Semiconductor | H11F1SM | H11F1SM
U8 |  | RS-232 Transceiver | Texas Instruments | SN65C3243DBR | SSOP-28-P0.65-B5.3
U9 |  | Photo FET Optocoupler | On Semiconductor | H11F1SM | H11F1SM
U10 |  | Amiga Audio Chip | 3M | 8452-11B1-RK-TP | PLCC-52
U11 |  | Amiga 8520 CIA | 3M | 8444-11B1-RK-TP | PLCC-44
U12 |  | AVR Microcontroller 16 MHz, 16 KB, 1 KB, 64 Pins, TQFP | Microchip | ATMEGA169PA-AUR | TQFP64_14x14MC
U13 |  | Dual JFET-input Operational Amplifier | Texas Instruments | OPA1642AIDGKT | MSOP8_MC
U14 |  | Analogue Switch, Dual Channel, 2 Channels, DPDT, 0.4 ohm | Analog Devices | ADG888YRUZ | TSSOP16
U15 |  | Single 2-input Positive-AND Gate | Texas Instruments | SN74LVC1G08DBVT | SOT-23-5
U16 |  | Amiga Graphics Controller | 3M | 8484-11B1-RK-TP | PLCC-84
U18 |  | Single 2-input Positive-AND Gate | Texas Instruments | SN74LVC1G08DBVT | SOT-23-5
U19 |  | I2C Controller for parallel bus | NXP | PCF8584T/2,512 | SOIC-20W
U20 |  | Amiga 1200 Memory Controller |  |  | QFT-128_0.8
U21 |  | Amiga 1200 GAL | 3M | 8420-11B1-RK-TP | PLCC-20
U22 |  | Single XOR Gate | Texas Instruments | SN74LVC1G86DBVR | SOT-23-5
U23 |  | Amiga 1200 Gayle Chip |  |  | PLCC-84
U24 |  | a 62408 rom in a DIL socket | Mill-Max Manufacturing Corp. | 117-43-642-41-005000 | DIP Socket 42
U25 |  | Single 2-input Positive-AND Gate | Texas Instruments | SN74LVC1G08DBVT | SOT-23-5
U27 |  | a 62408 rom in a DIL socket | Mill-Max Manufacturing Corp. | 117-43-642-41-005000 | DIP Socket 42
U28 |  | Single 2-input Positive-AND Gate | Texas Instruments | SN74LVC1G08DBVT | SOT-23-5
U29 |  | Amiga DMA Controller | 3M | 8484-11B1-RK-TP | PLCC-84
U30 |  | Single 2-input Positive-AND Gate | Texas Instruments | SN74LVC1G08DBVT | SOT-23-5
U17 | +5V | Fixed LDO Voltage Regulator 5V out / 26V in | ROHM Semiconductor | BD50C0AFP-CE2 | TO252
U26 | 12V | DC-DC Convertor 12V 10W | Meanwell | SKM10E-12 | SKM10E
VR1 | 5V | Varistor | AVX | VCUG080050L1DP | 0805
X1 |  |  |  |  | OscSocket

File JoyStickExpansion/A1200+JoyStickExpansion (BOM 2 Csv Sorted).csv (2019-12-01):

Name | Value | Desc | Mfr | Part Number | Footprint
C30 | 1µF/50V | 1µF/50V Ceramic Capacitor 0805 | Murata | GRM21BR71H105KA12L | C0805
C15 | 4.7µF/100V | 4.7µF/100V Ceramic Capacitor 0805 | AVX | 12061Z475KAT2A | C0805
C16 | 4.7µF/100V | 4.7µF/100V Ceramic Capacitor 0805 | AVX | 12061Z475KAT2A | C0805
C17 | 4.7µF/100V | 4.7µF/100V Ceramic Capacitor 0805 | AVX | 12061Z475KAT2A | C0805
C4 | 10µF/16V | 10µF/16V Ceramic Capacitor 0805 | Murata | GRM219R61C106KA73D | C0805
C5 | 10µF/16V | 10µF/16V Ceramic Capacitor 0805 | Murata | GRM219R61C106KA73D | C0805
C24 | 10µF/16V | 10µF/16V Ceramic Capacitor 0805 | Murata | GRM219R61C106KA73D | C0805
C6 | 100 nF | 3 Pin Capacitor | Murata | NFM21PC104R1E3D | NFM21
C7 | 100 nF | 3 Pin Capacitor | Murata | NFM21PC104R1E3D | NFM21
C8 | 100 nF | 3 Pin Capacitor | Murata | NFM21PC104R1E3D | NFM21
C9 | 100 nF | 3 Pin Capacitor | Murata | NFM21PC104R1E3D | NFM21
C10 | 100 nF | 3 Pin Capacitor | Murata | NFM21PC104R1E3D | NFM21
C11 | 100 nF | 3 Pin Capacitor | Murata | NFM21PC104R1E3D | NFM21
C14 | 100 nF | 3 Pin Capacitor | Murata | NFM21PC104R1E3D | NFM21
C18 | 100 nF | 3 Pin Capacitor | Murata | NFM21PC104R1E3D | NFM21
C19 | 100 nF | 3 Pin Capacitor | Murata | NFM21PC104R1E3D | NFM21
C20 | 100 nF | 3 Pin Capacitor | Murata | NFM21PC104R1E3D | NFM21
C21 | 100 nF | 3 Pin Capacitor | Murata | NFM21PC104R1E3D | NFM21
C22 | 100 nF | 3 Pin Capacitor | Murata | NFM21PC104R1E3D | NFM21
C23 | 100 nF | 3 Pin Capacitor | Murata | NFM21PC104R1E3D | NFM21
C25 | 100 nF | 3 Pin Capacitor | Murata | NFM21PC104R1E3D | NFM21
C26 | 100 nF | 3 Pin Capacitor | Murata | NFM21PC104R1E3D | NFM21
C27 | 100 nF | 3 Pin Capacitor | Murata | NFM21PC104R1E3D | NFM21
C29 | 100 nF | 3 Pin Capacitor | Murata | NFM21PC104R1E3D | NFM21
C32 | 100 nF | 3 Pin Capacitor | Murata | NFM21PC104R1E3D | NFM21
C33 | 100 nF | 3 Pin Capacitor | Murata | NFM21PC104R1E3D | NFM21
C1 | 100nF/50V | 100nF/50V Ceramic Capacitor 0805 | AVX | 08055C104KAZ2A | C0805
C2 | 100nF/50V | 100nF/50V Ceramic Capacitor 0805 | AVX | 08055C104KAZ2A | C0805
C28 | 100nF/50V | 100nF/50V Ceramic Capacitor 0805 | AVX | 08055C104KAZ2A | C0805
C31 | 100nF/50V | 100nF/50V Ceramic Capacitor 0805 | AVX | 08055C104KAZ2A | C0805
D1 |  | Green Red 0805 | KINGBRIGHT | KP-2012MGC | 0805LED
D2 |  | Green Red 0805 | KINGBRIGHT | KP-2012MGC | 0805LED
D3 |  | Green Red 0805 | KINGBRIGHT | KP-2012MGC | 0805LED
D4 | 5V | 4 Channel TVS Diodes | Wurth Elektronik | 82402374 | SC70-5
D5 | 5V | 4 Channel TVS Diodes | Wurth Elektronik | 82402374 | SC70-5
D6 | 5V | 4 Channel TVS Diodes | Wurth Elektronik | 82402374 | SC70-5
D7 | 5V | 4 Channel TVS Diodes | Wurth Elektronik | 82402374 | SC70-5
I1 | 10 mA | Constant Current Regulator | ON Semiconductor | NSI50010YT1GOSCT-ND | SOD-123
I2 | 10 mA | Constant Current Regulator | ON Semiconductor | NSI50010YT1GOSCT-ND | SOD-123
J1 |  | Board to Board & Mezzanine Connectors 40P 1.27 SMC Female R/A SMT Type | HARWIN | M55-6104042R | M55-6104042R
J2 |  | Board to Board & Mezzanine Connectors 40P 1.27 SMC Female R/A SMT Type | HARWIN | M55-6104042R | M55-6104042R
J4 |  | DE-09 Male Right Angle Connector | NorComp | 682-009-113R531 | DE-09 Male Right Angle
J5 |  | DE-09 Male Right Angle Connector | NorComp | 682-009-113R531 | DE-09 Male Right Angle
J6 |  | 10/100BaseT RJ45 LAN Connector with integrated transformer | WURTH ELEKTRONIK | 74990111217 | 74990111217
J7 |  | USB Connector Type A | WURTH ELEKTRONIK | 61400416021 | USB Type A
J8 |  | Programming header for AVR MCUs |  |  | TC2030
J9 |  | 8 Pin SIL | AMP - TE CONNECTIVITY | 825433-8 | SIL-8-2.54
L1 | 0.95 µH | chip ferrite bead | TE CONNECTIVITY | BMB2A0600BN3 | 0805
L2 | 0.95 µH | chip ferrite bead | TE CONNECTIVITY | BMB2A0600BN3 | 0805
Q1 | 30V, 5A | MOSFET, N Channel, 5A, 30V | Infineon | IRLML6344TRPBF | SOT-23
Q2 | 30V, 5A | MOSFET, N Channel, 5A, 30V | Infineon | IRLML6344TRPBF | SOT-23
R8 | 3K01 | Resistor Thick Film 0.1W 1% |  |  | R0805
R1 | 4K7 | Resistor Network | Bourns | CAY17-472JALF | YC158
R7 | 4K7 | Resistor Thick Film 0.1W 1% |  |  | R0805
R14 | 4K7 | Resistor Thick Film 0.1W 1% |  |  | R0805
R15 | 4K7 | Resistor Thick Film 0.1W 1% |  |  | R0805
R13 | 10K | Resistor Thick Film 0.1W 1% |  |  | R0805
R11 | 22R | Resistor Thick Film 0.1W 1% |  |  | R0805
R12 | 22R | Resistor Thick Film 0.1W 1% |  |  | R0805
R3 | 49R9 | Resistor Thick Film 0.1W 1% |  |  | R0805
R4 | 49R9 | Resistor Thick Film 0.1W 1% |  |  | R0805
R5 | 49R9 | Resistor Thick Film 0.1W 1% |  |  | R0805
R6 | 49R9 | Resistor Thick Film 0.1W 1% |  |  | R0805
R9 | 220R | Resistor Thick Film 0.1W 1% |  |  | R0805
R10 | 220R | Resistor Thick Film 0.1W 1% |  |  | R0805
SW1 |  | Tictile Switch | Panasonic | EVQ-6Q201W | EVQP0
U1 |  | Analogue Switch, Dual Channel, 2 Channels, DPDT, 0.4 ohm | Analog Devices | ADG888YRUZ | TSSOP16
U3 |  | Ethernet Controller 100 Mbps | Microchip | KSZ8851-16MLL | TQFP-48-0.5
U4 |  | Analogue Switch, Dual Channel, 2 Channels, DPDT, 0.4 ohm | Analog Devices | ADG888YRUZ | TSSOP16
U6 |  | 8-bit dual supply Translating Transceiver with 3-state outputs | Nexperia | 74LVC8T245PW,118 | TSSOP-24
U7 |  | 8-bit dual supply Translating Transceiver with 3-state outputs | Nexperia | 74LVC8T245PW,118 | TSSOP-24
U8 |  | 8-bit dual supply Translating Transceiver with 3-state outputs | Nexperia | 74LVC8T245PW,118 | TSSOP-24
U9 |  | 8-bit Atmel | Microchip | AT90USB1287-AU | TQFP-64
Microcontroller
with
64/128 Kbytes
of ISP Flash
and USB
Controller
U10 |  | REGISTER | Nexperia | 74HC166D-Q100J | SOIC16
U2 | +3.3V | Fixed LDO Voltage Regulator 3.3V | Texas Instruments | LP38691DT-3.3/NOPB | TO252
X2 | 16 MHZ | Crystal Oscillator | Epson | 1G0041710027 SG-210STF 16 MHZ L | EPSON SG210
X1 | 25 MHZ | Crystal Oscillator | Epson | X1G0041710033 SG-210STF 25 MHZ L | EPSON SG210

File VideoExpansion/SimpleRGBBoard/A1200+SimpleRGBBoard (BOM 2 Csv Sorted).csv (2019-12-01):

Name | Value | Desc | Mfr | Part Number | Footprint
C12 | 1µF/50V | 1µF/50V Ceramic Capacitor 0805 | Murata | GRM21BR71H105KA12L | C0805
C2 | 10µF/16V | 10µF/16V Ceramic Capacitor 0805 | Murata | GRM219R61C106KA73D | C0805
C6 | 10µF/16V | 10µF/16V Ceramic Capacitor 0805 | Murata | GRM219R61C106KA73D | C0805
C10 | 10nF/50V | 10nF/50V Ceramic Capacitor 0805 | AVX | 08055C103KAT2A | 0805
C11 | 10nF/50V | 10nF/50V Ceramic Capacitor 0805 | AVX | 08055C103KAT2A | 0805
C14 | 10nF/50V | 10nF/50V Ceramic Capacitor 0805 | AVX | 08055C103KAT2A | 0805
C3 | 100nF | 3 Pin Capacitor | Murata | NFM21PC104R1E3D | NFM21
C4 | 100nF | 3 Pin Capacitor | Murata | NFM21PC104R1E3D | NFM21
C7 | 100nF | 3 Pin Capacitor | Murata | NFM21PC104R1E3D | NFM21
C1 | 100nF/50V | 100nF/50V Ceramic Capacitor 0805 | MURATA | GCM21BR72A104KA37L | 0805
C5 | 100nF/50V | 100nF/50V Ceramic Capacitor 0805 | MURATA | GCM21BR72A104KA37L | 0805
C8 | 100nF/50V | 100nF/50V Ceramic Capacitor 0805 | MURATA | GCM21BR72A104KA37L | 0805
C9 | 100nF/50V | 100nF/50V Ceramic Capacitor 0805 | MURATA | GCM21BR72A104KA37L | 0805
C13 | 100nF/50V | 100nF/50V Ceramic Capacitor 0805 | AVX | 08055C104KAZ2A | C0805
J1 |  | FH-Board To Board Connector Receptacle | TE Connectivity | 5120523-1 | Free Height (FH) Receptacle 64
J2 |  | FH-Board To Board Connector Receptacle | TE Connectivity | 5120523-1 | Free Height (FH) Receptacle 64
J3 |  | D Sub Connector, Right Angle, HD26, 26 Contacts, Plug, Through Hole, DA, Steel Body | Harting | 09562627813 | DB-26 RA Male
L1 | 0.95 µH | chip ferrite bead | TE CONNECTIVITY | BMB2A0600BN3 | 0805
L2 | 0.95 µH | chip ferrite bead | TE CONNECTIVITY | BMB2A0600BN3 | 0805
R8 | 1K | Resistor Thick Film 0.1W 1% |  |  | R0805
R7 | 68 | Resistor Thick Film 0.1W 1% |  |  | R0805
R1 | 75 | Resistor Thick Film 0.1W 1% |  |  | R0805
R2 | 75 | Resistor Thick Film 0.1W 1% |  |  | R0805
R4 | 75 | Resistor Thick Film 0.1W 1% |  |  | R0805
R5 | 75 | Resistor Thick Film 0.1W 1% |  |  | R0805
R6 | 75 | Resistor Thick Film 0.1W 1% |  |  | R0805
R3 | 360 | Resistor Thick Film 0.1W 1% |  |  | R0805
R9 | 530R | Resistor Thick Film 0.1W 1% |  |  | R0805
U1 |  | Triple 8-Bit High Speed Video DAC | Analog Devices | ADV7125JSTZ240 | TQFP-48-0.5
U2 |  | 8-bit dual supply Translating Transceiver with 3-state outputs | Nexperia | 74LVC8T245PW,118 | TSSOP-24
U3 | 1.235V | Voltage reference | Texas Instruments | LM385M3-1.2 | SOT-23

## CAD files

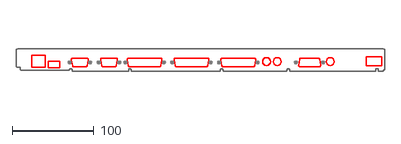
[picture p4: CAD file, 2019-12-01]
BackplateA.dxf
450.0 x 28.0

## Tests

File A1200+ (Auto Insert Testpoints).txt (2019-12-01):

Auto Insert Testpoints
----------------------

Report Written : 23/11/2019 12:07:58
Design Path    : X:\Personal\Amiga1200Plus\A1200+.sch
Design Title   : A1200+
Created        : 26/06/2018 20:48:32
Last Saved     : 6/10/2019 14:44:09
Editing Time   : 21110 min

Summary
-------

   0 net(s) missing testpoints
   0 net(s) with extra testpoints

                ---------------- End Of Report ----------------

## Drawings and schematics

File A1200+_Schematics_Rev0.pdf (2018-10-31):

# ABCD

# ABCD

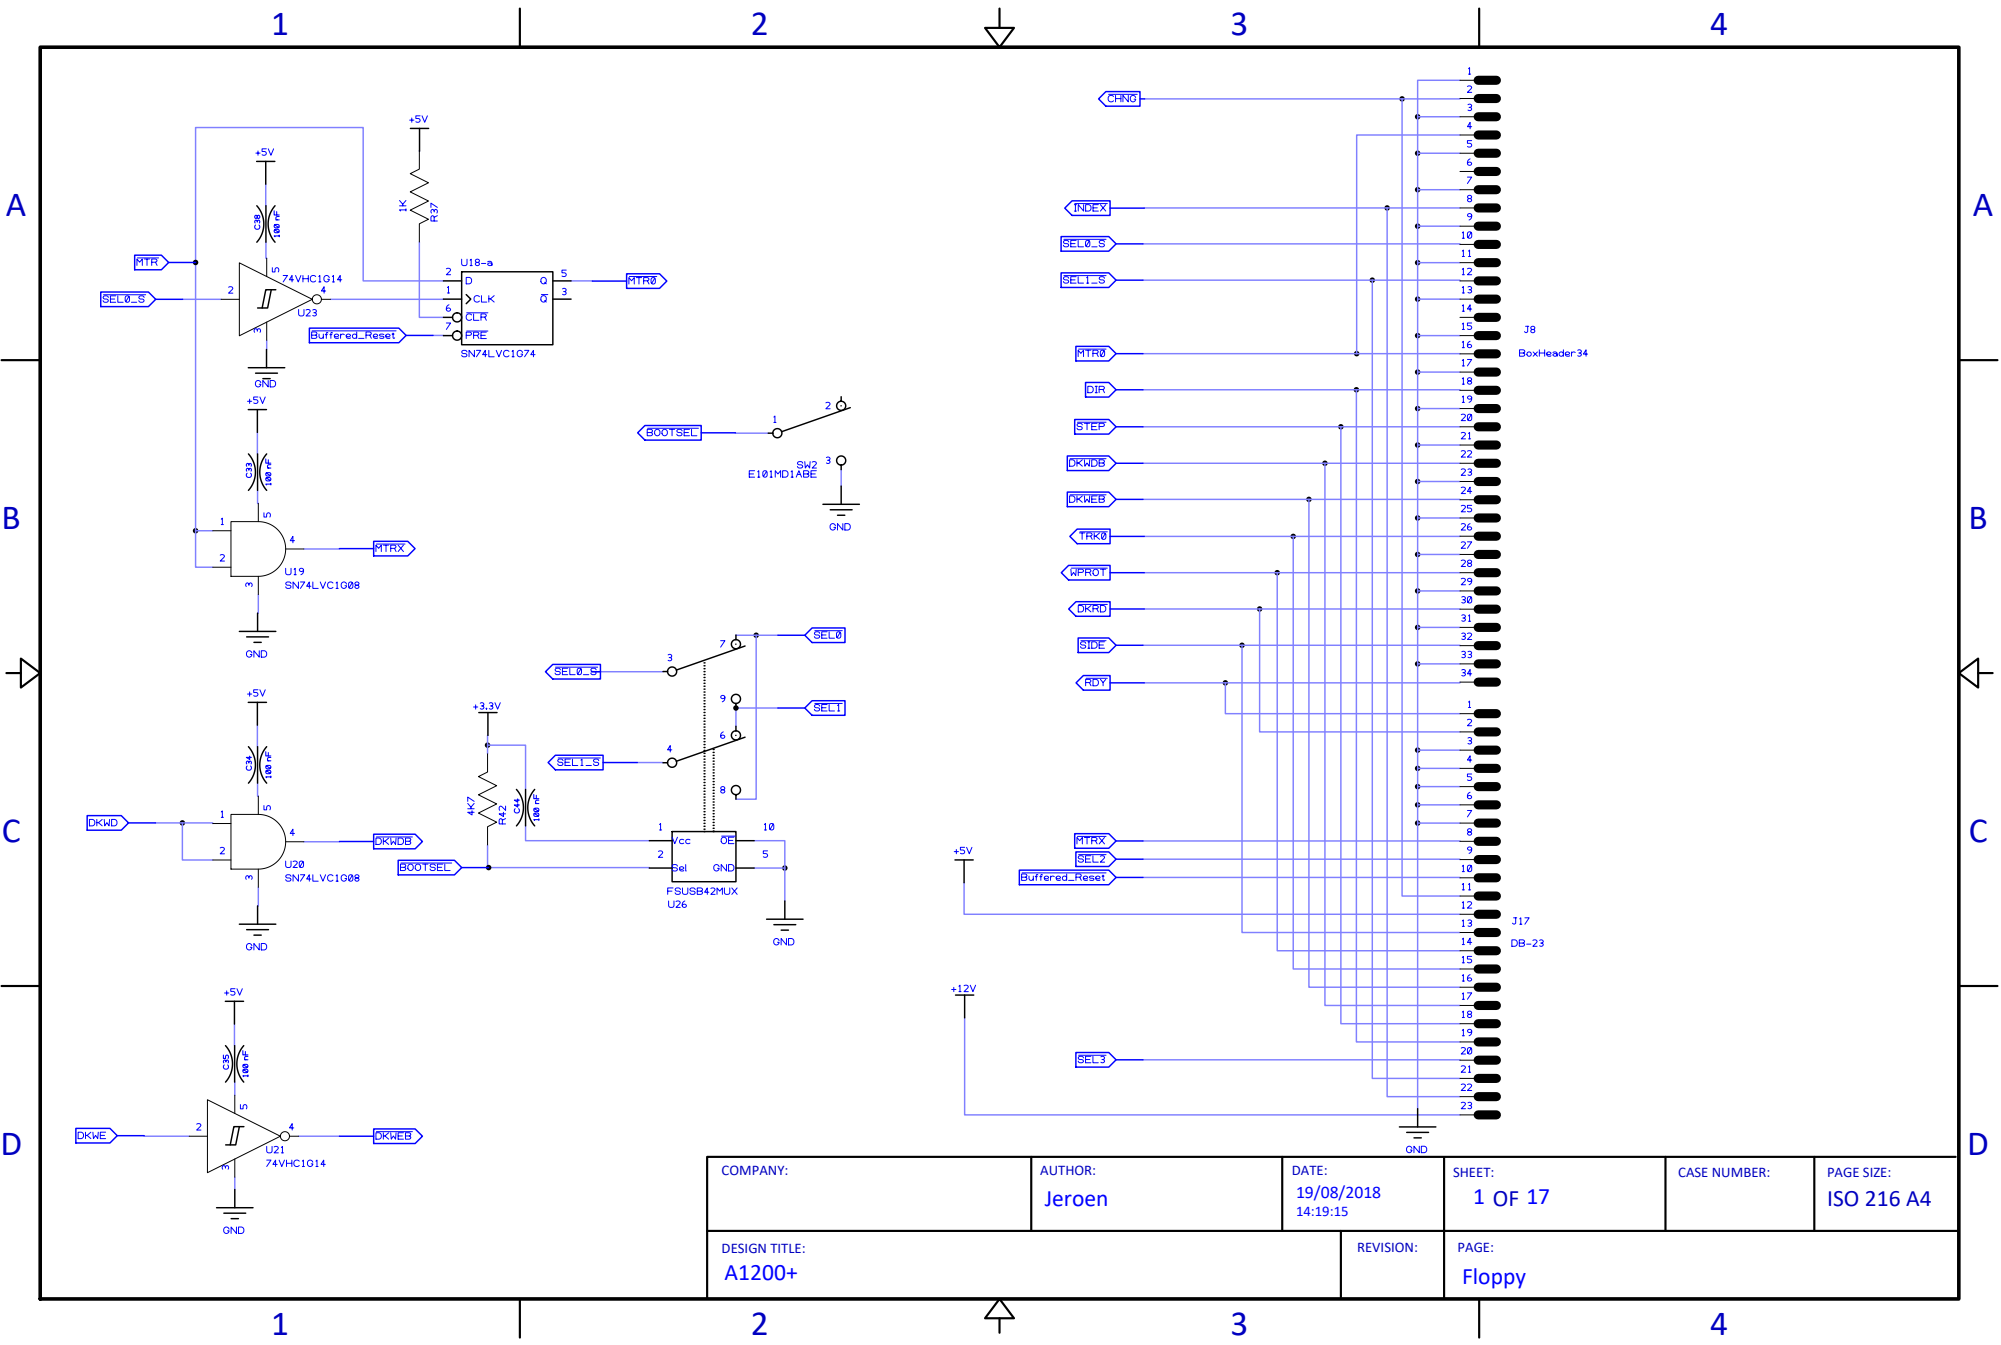
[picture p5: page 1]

# ABCD

# ABCD

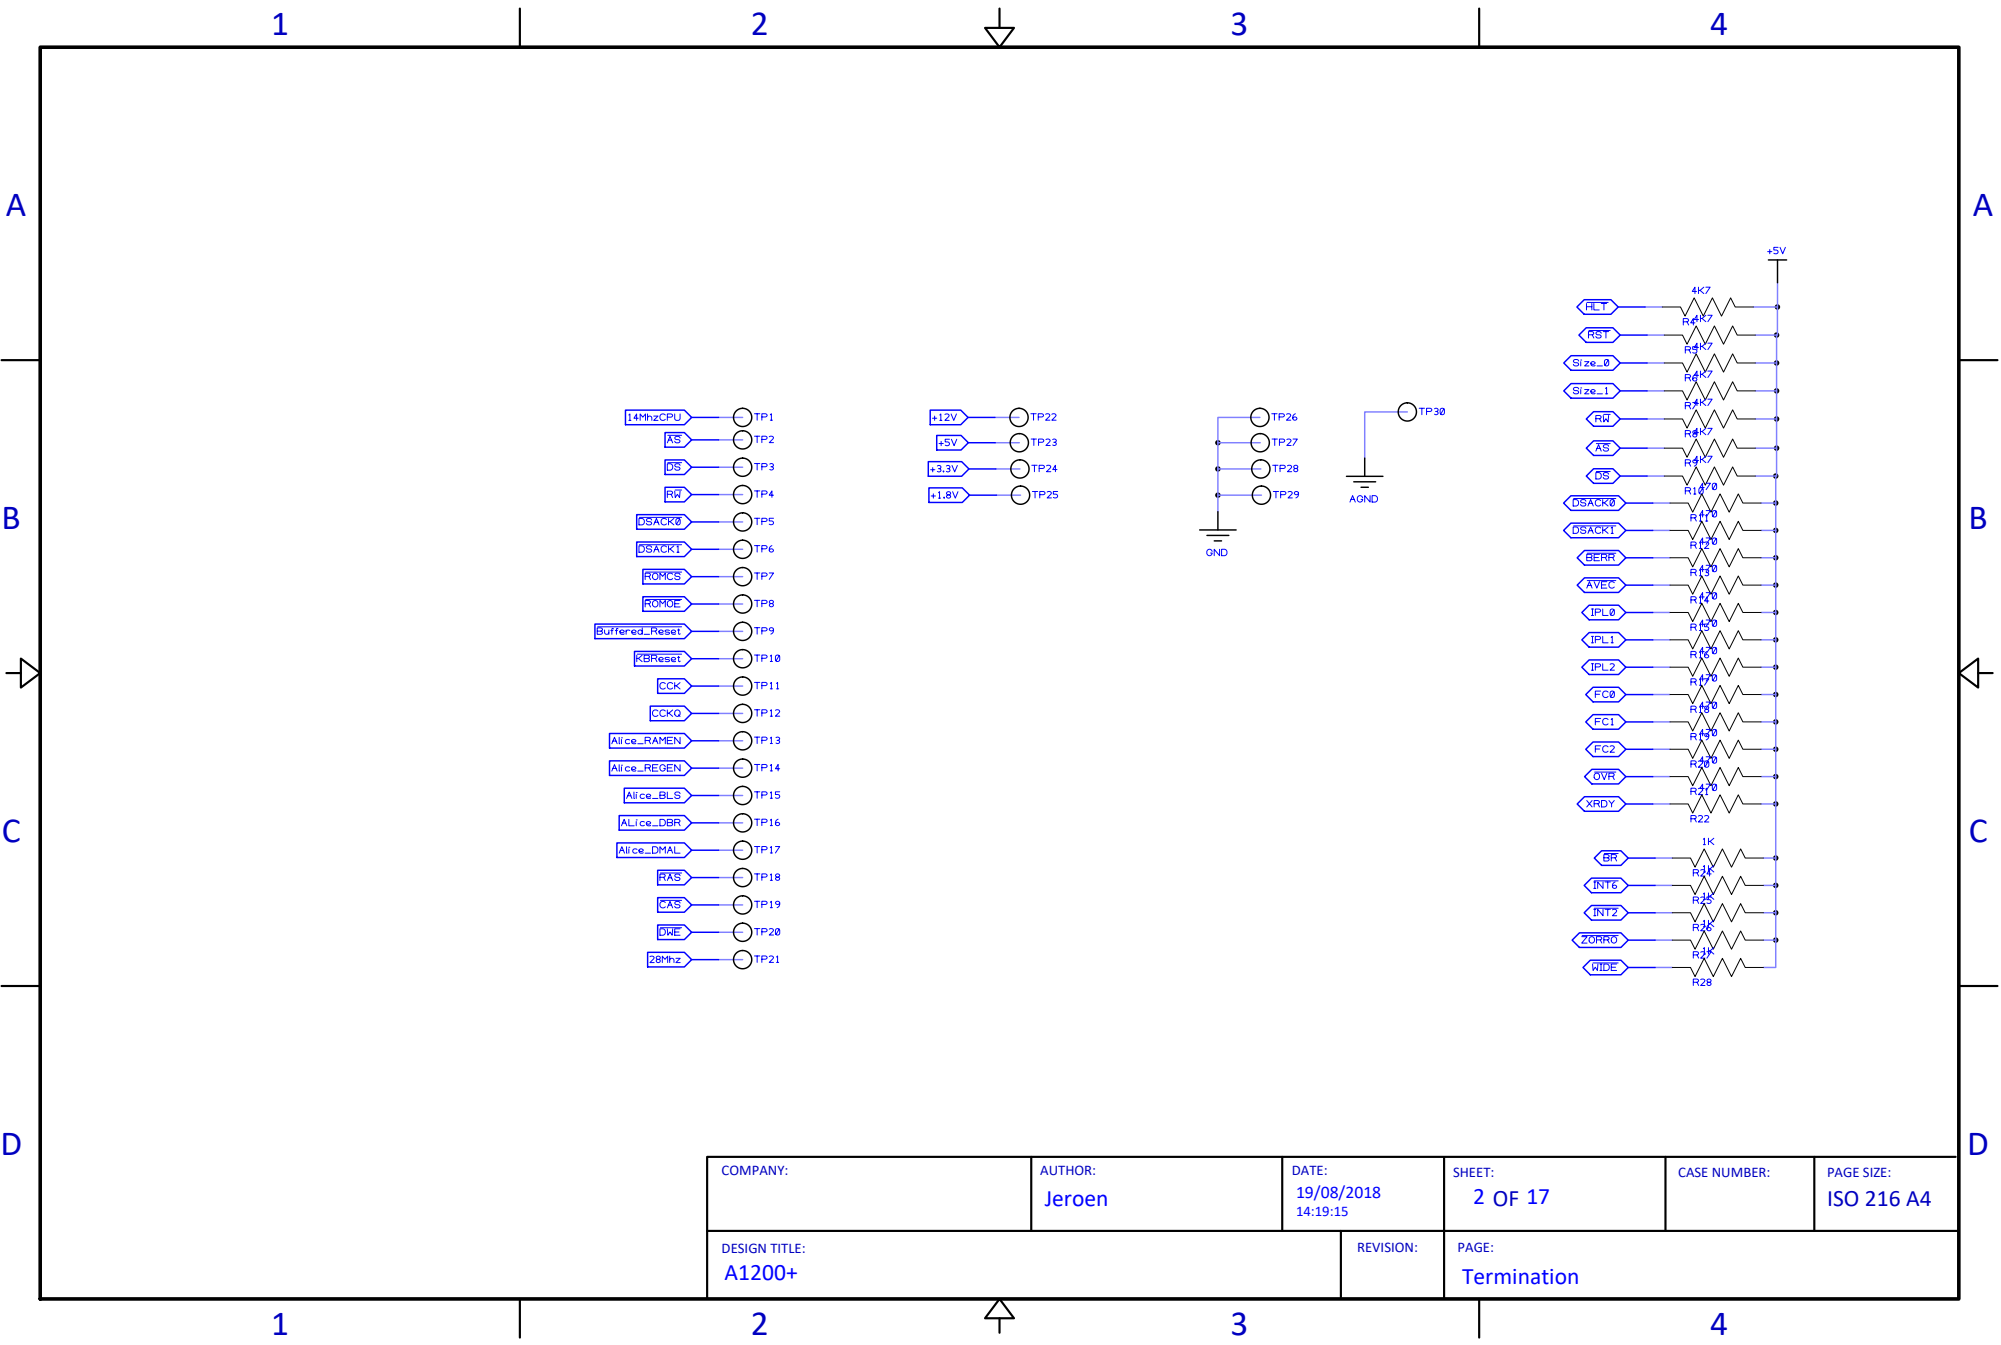
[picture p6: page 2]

# ABCD

# ABCD

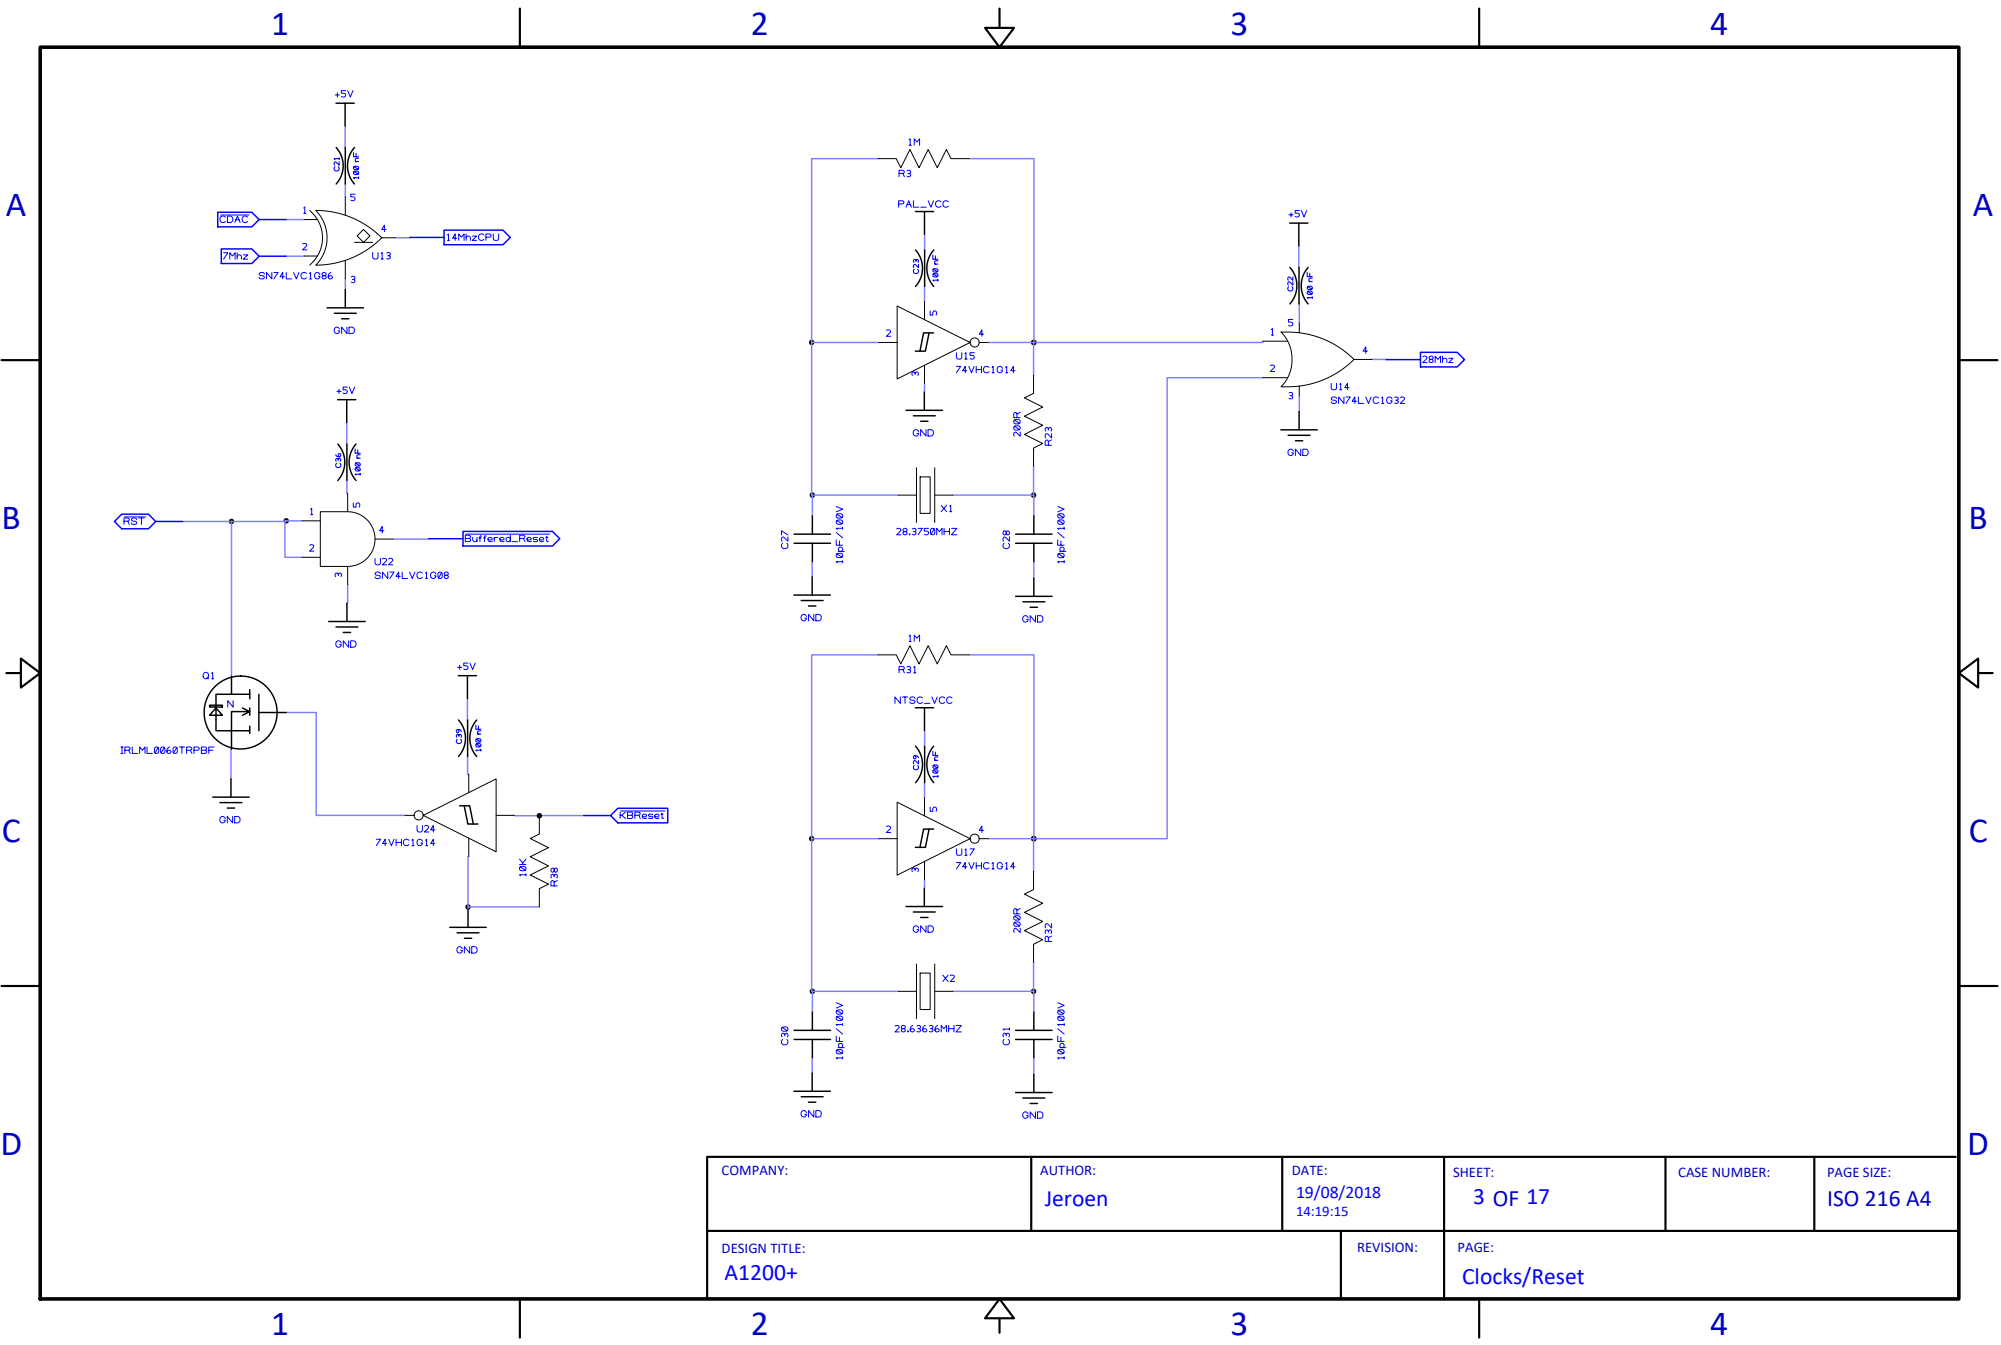
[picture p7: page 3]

A

1 | 2 | 3 | 4

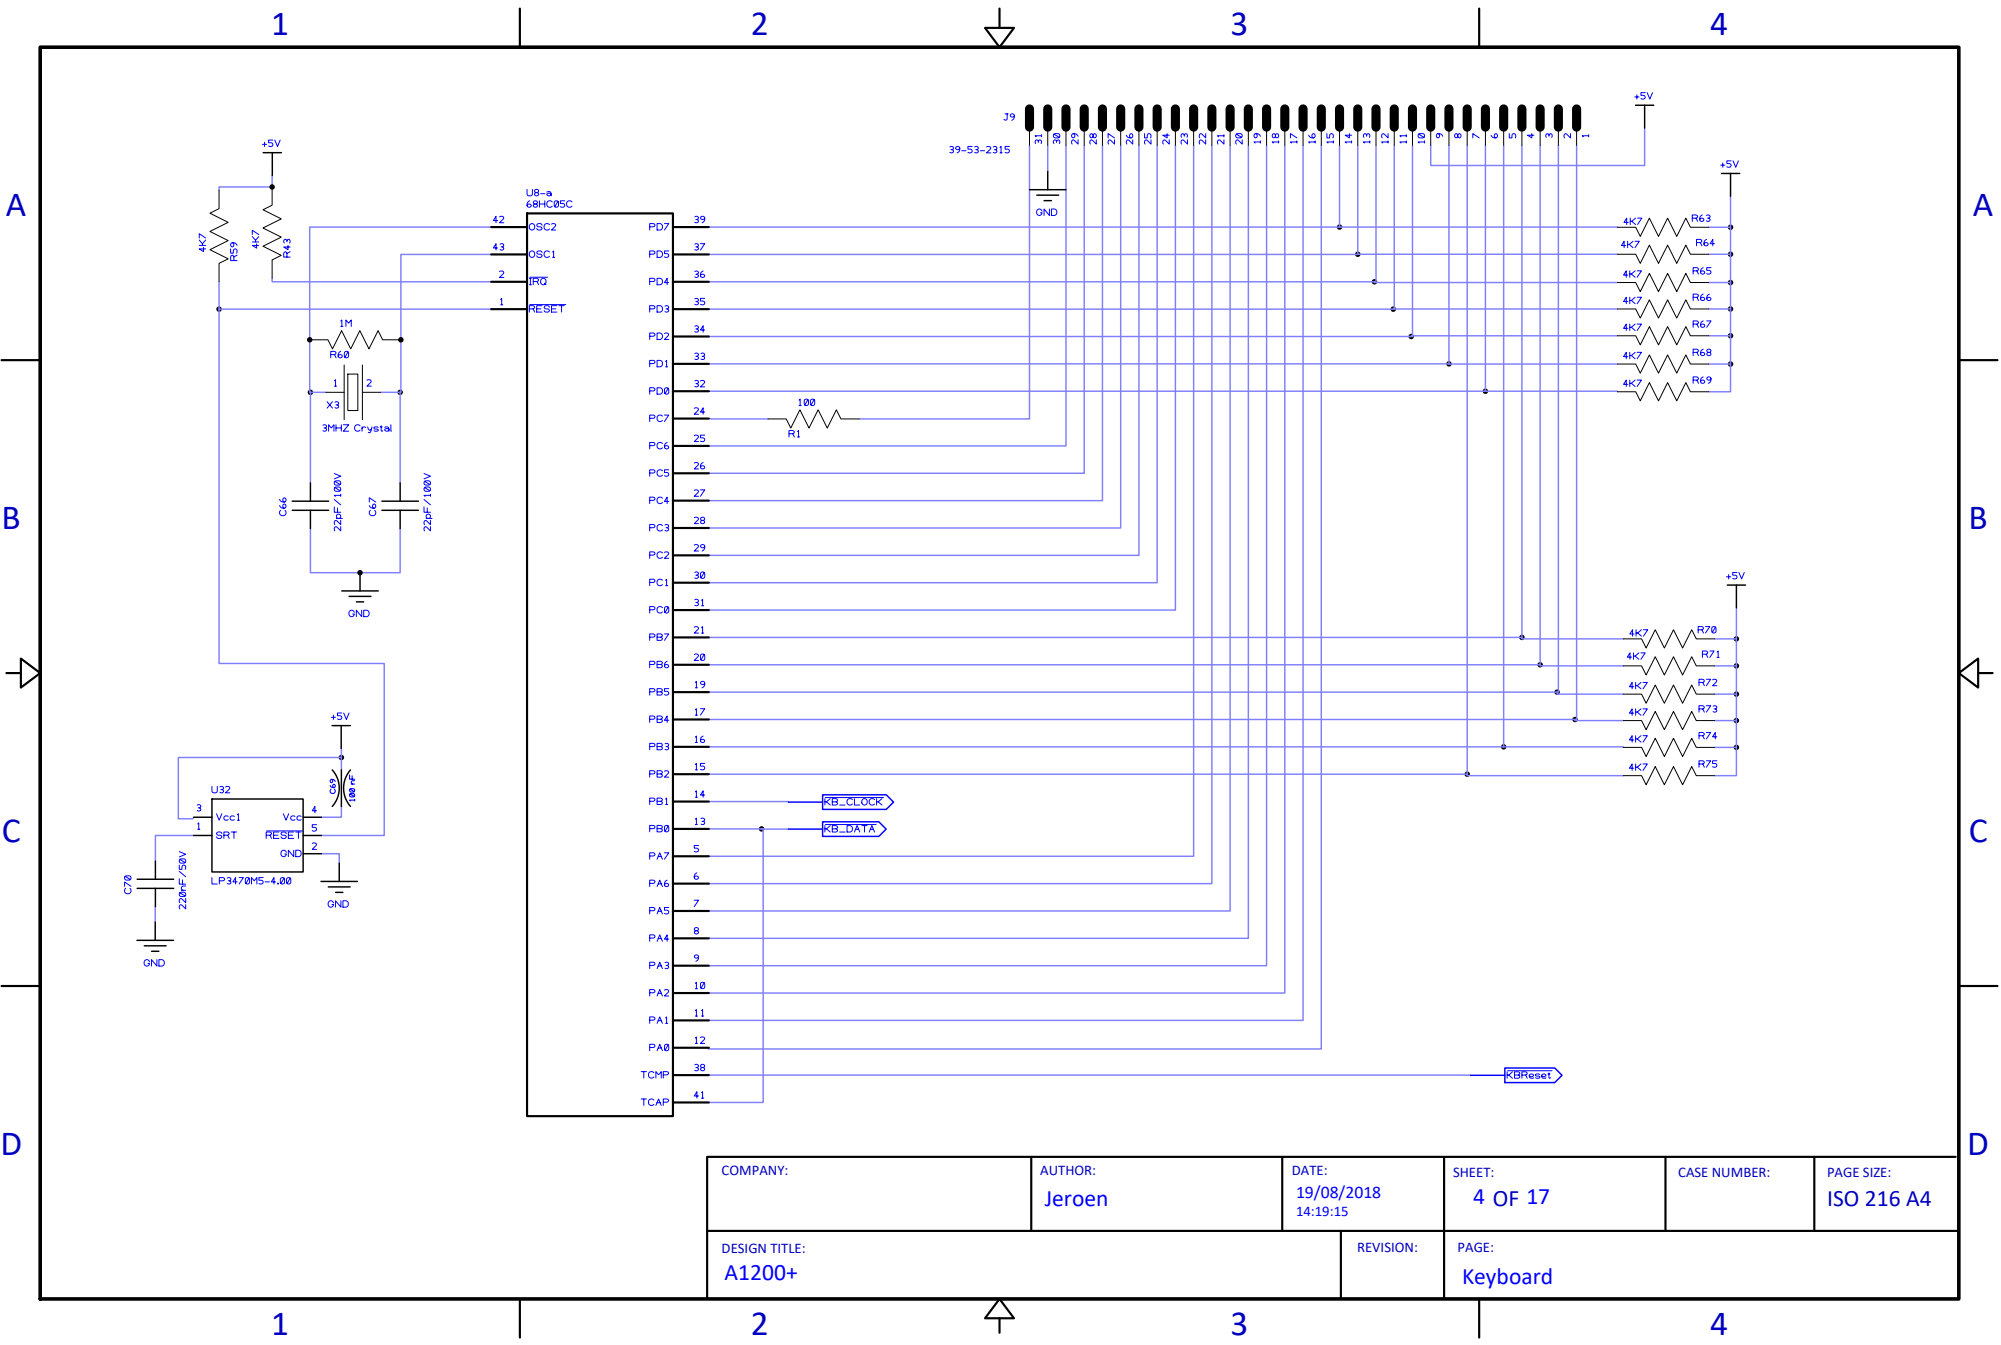
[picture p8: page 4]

# ABCD

# ABCD

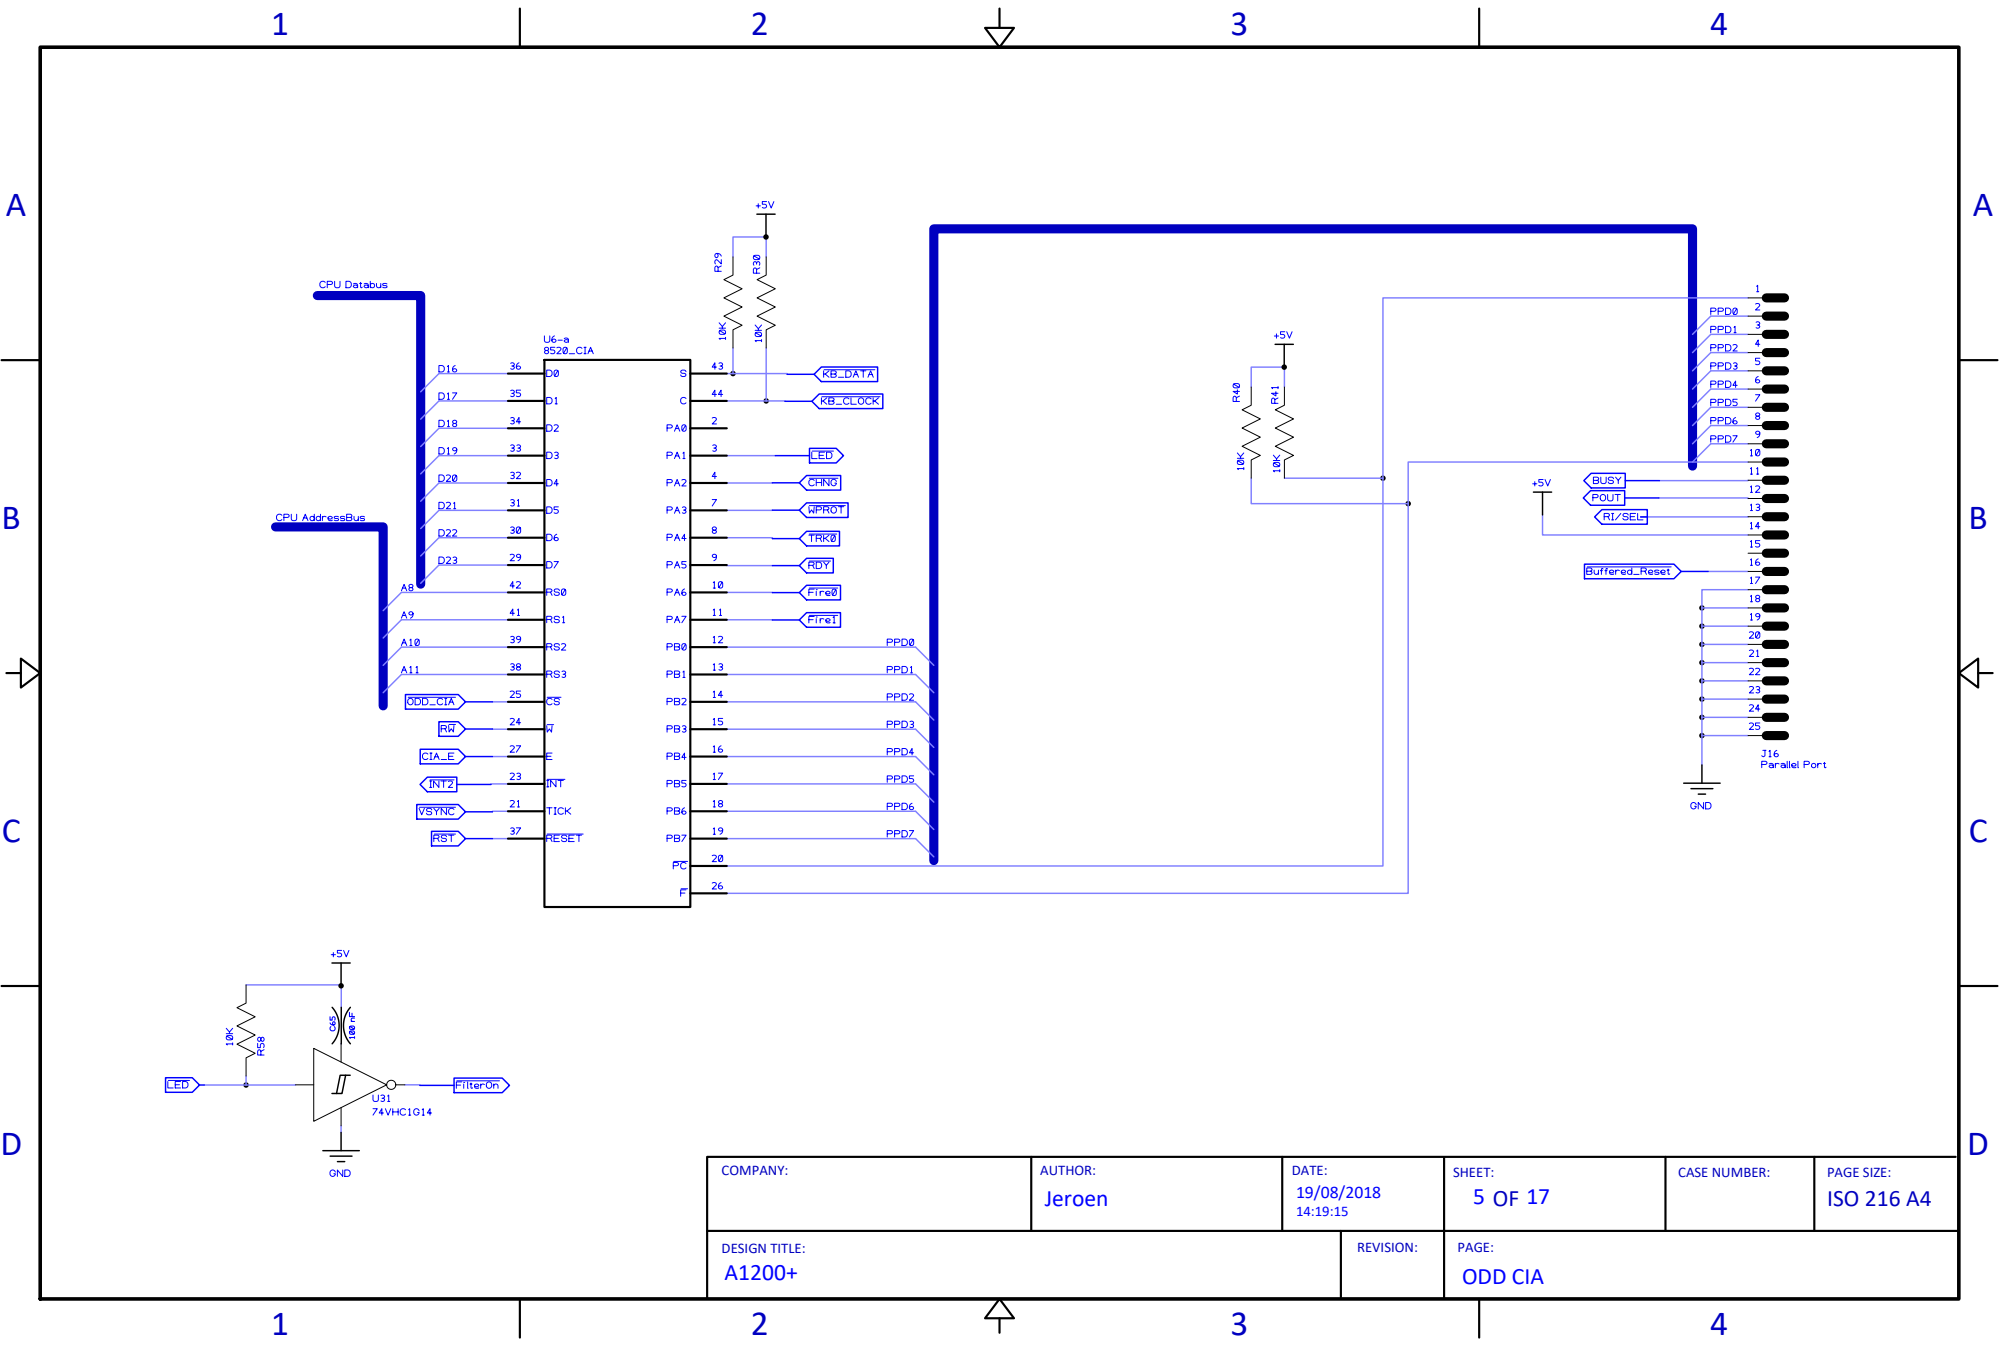
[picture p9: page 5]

# ABCD

# ABCD

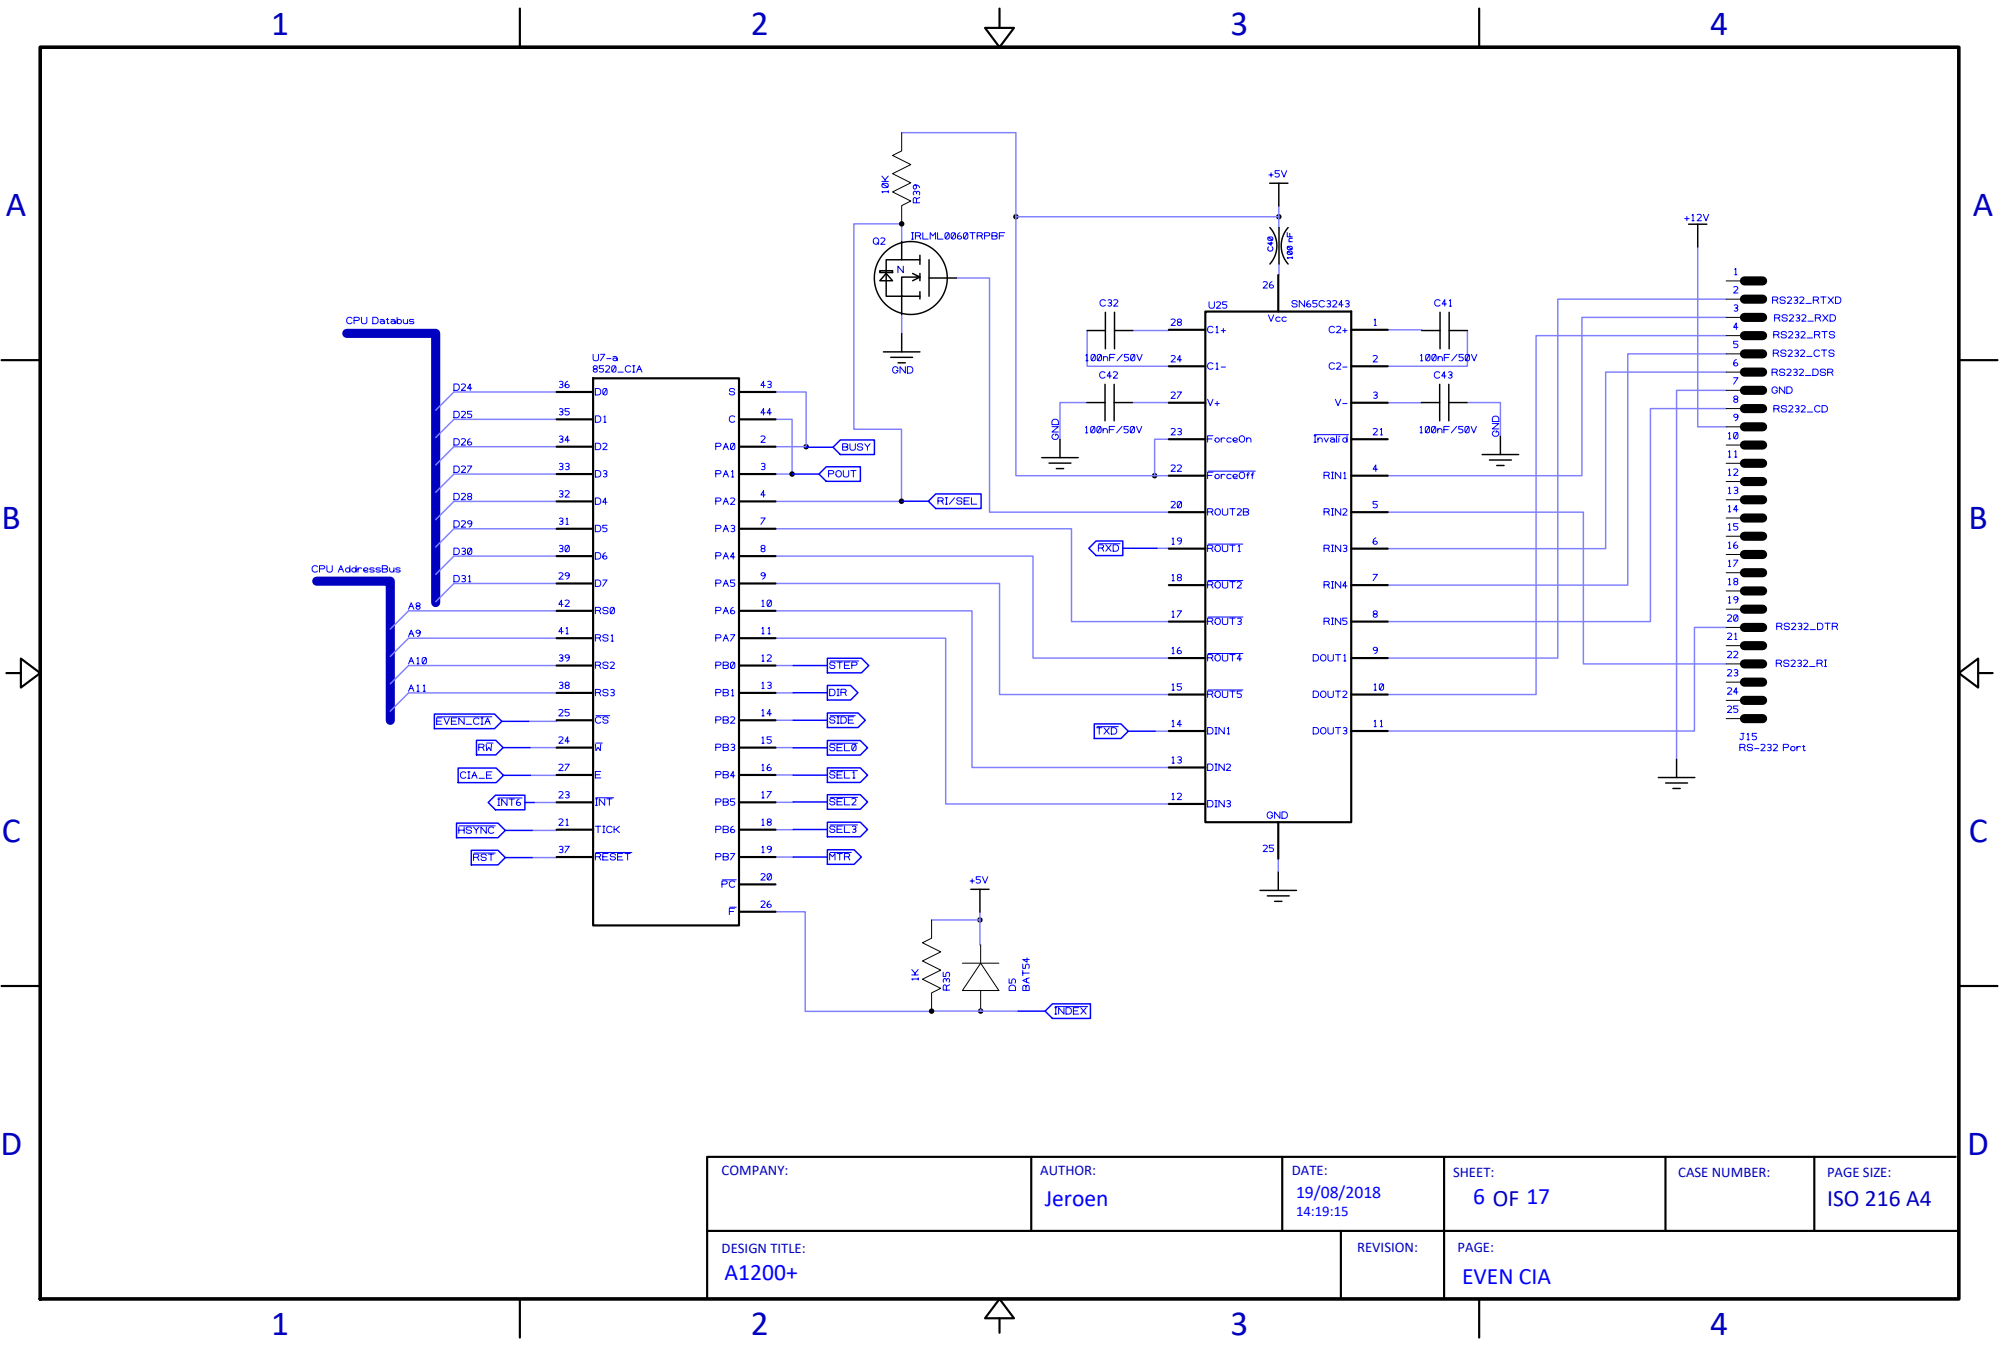
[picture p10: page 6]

A

1 | 2 | 3 | 4

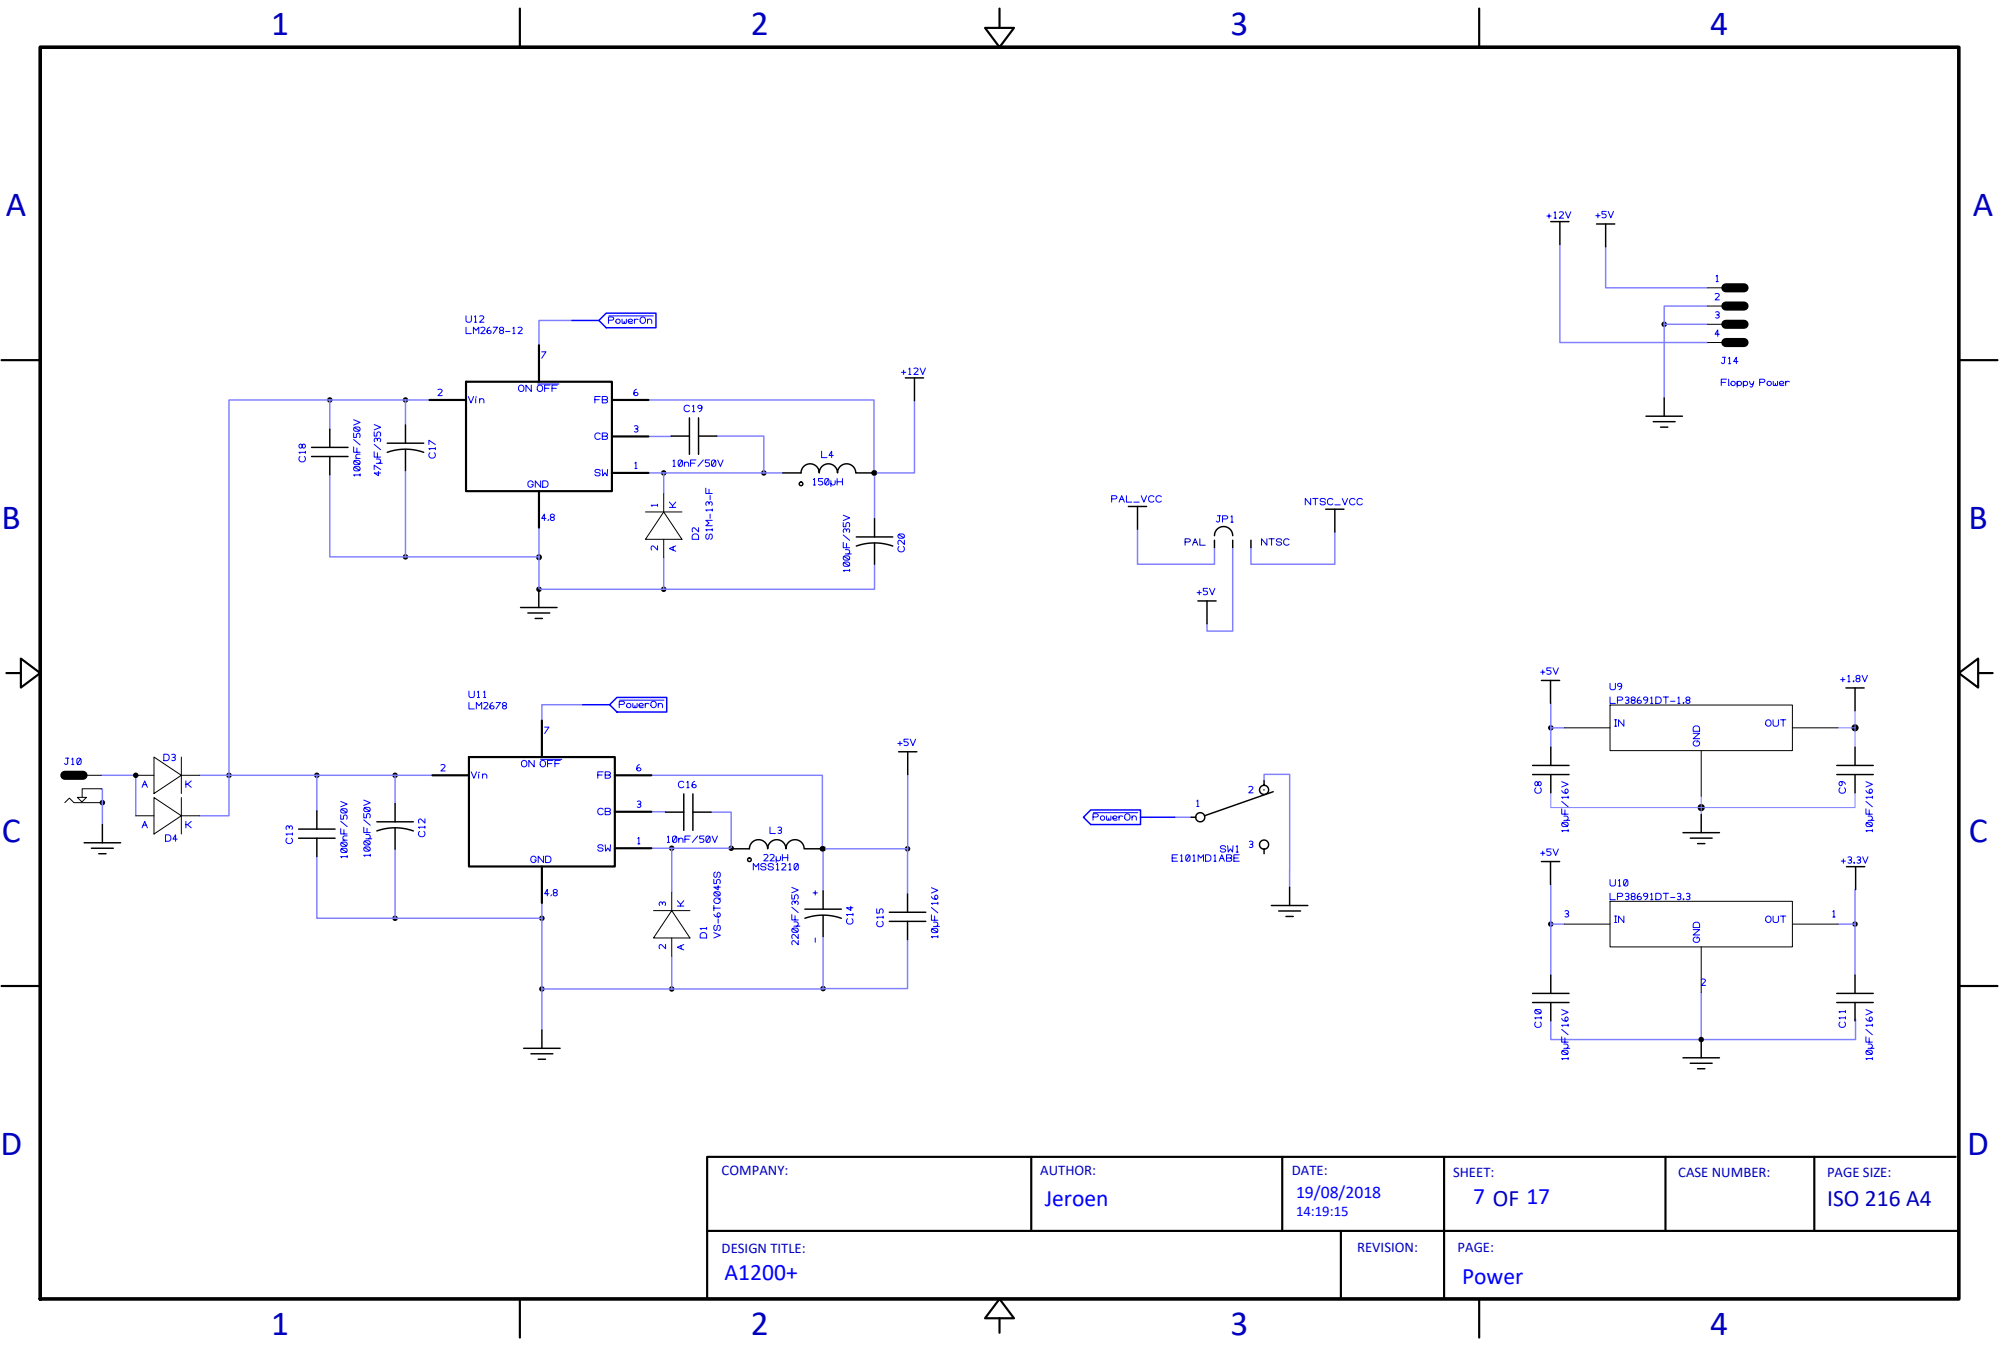
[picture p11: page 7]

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

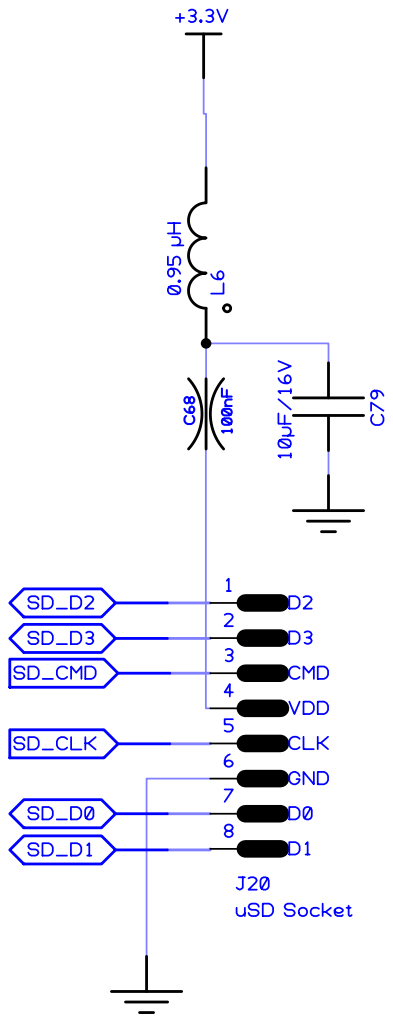
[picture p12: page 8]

A

1 | 2 | 3 | 4

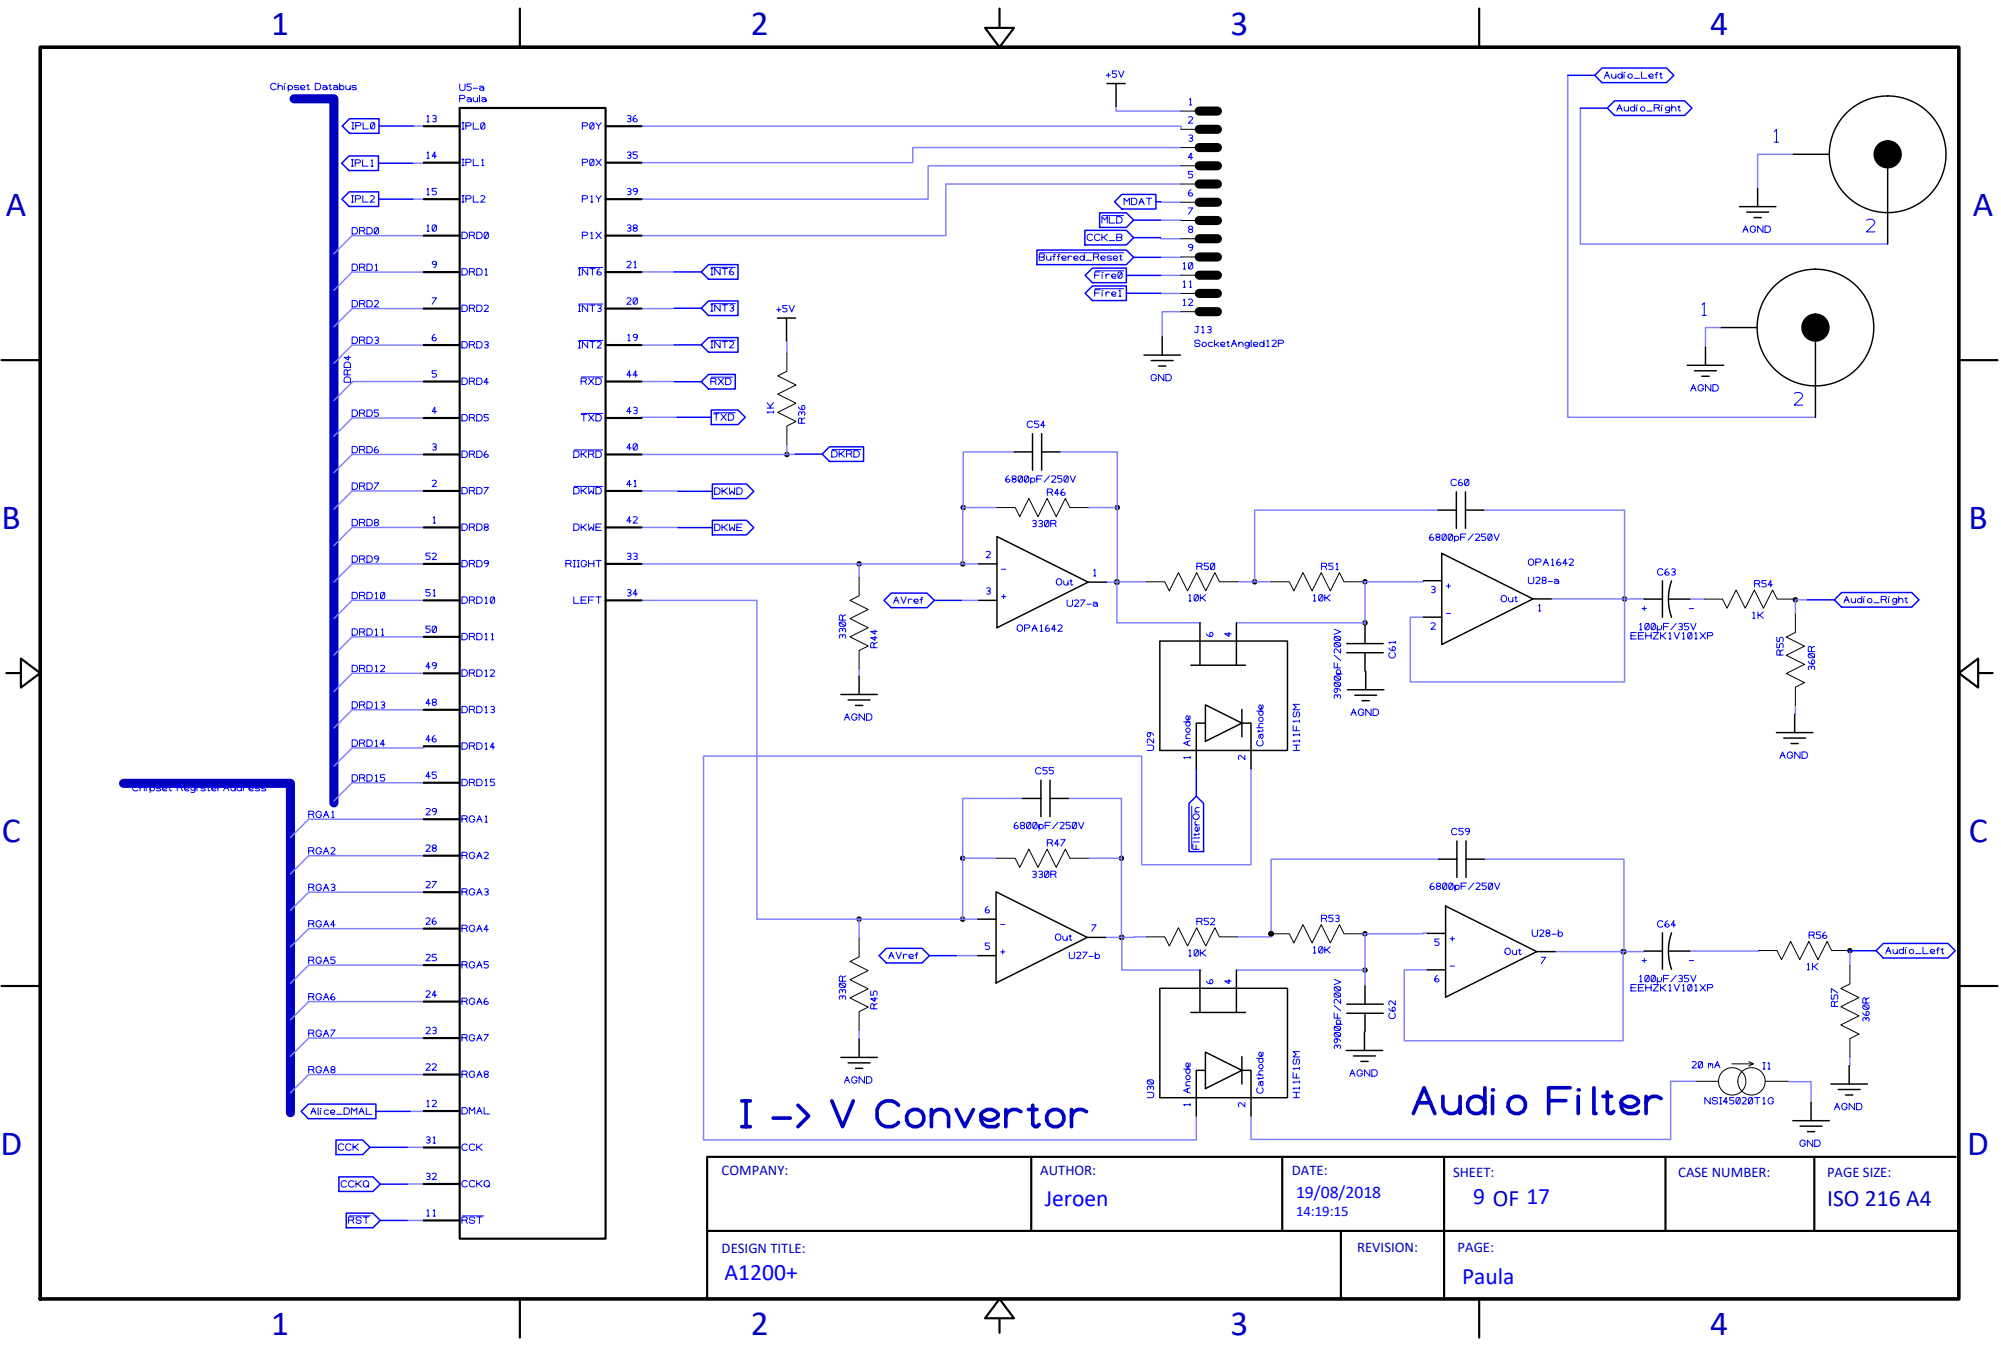
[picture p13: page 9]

# ABCD

# ABCD

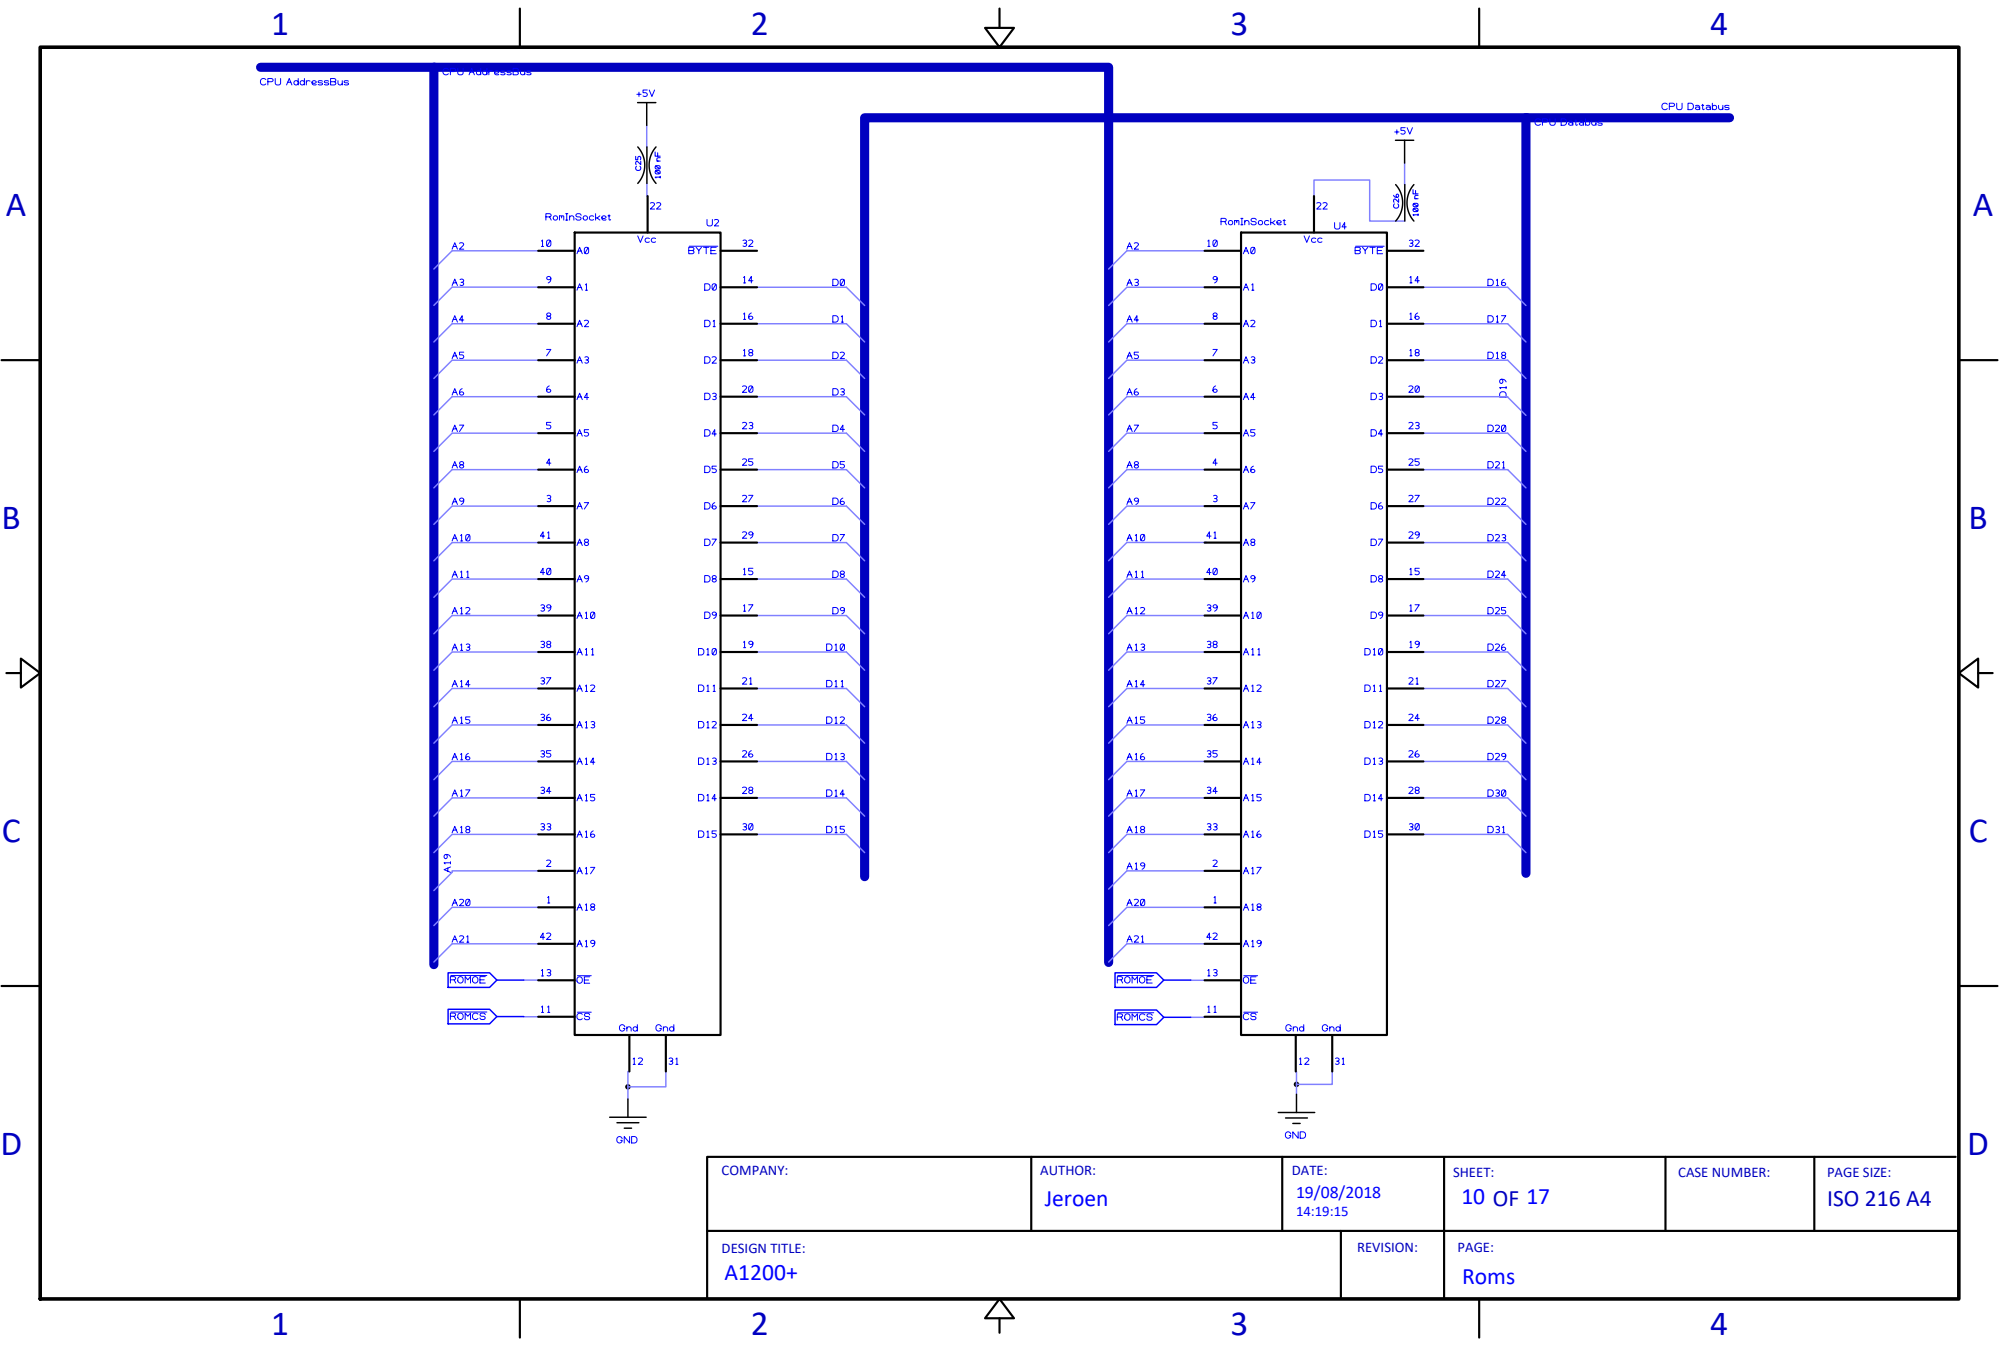
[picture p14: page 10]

# ABCD

# ABCD

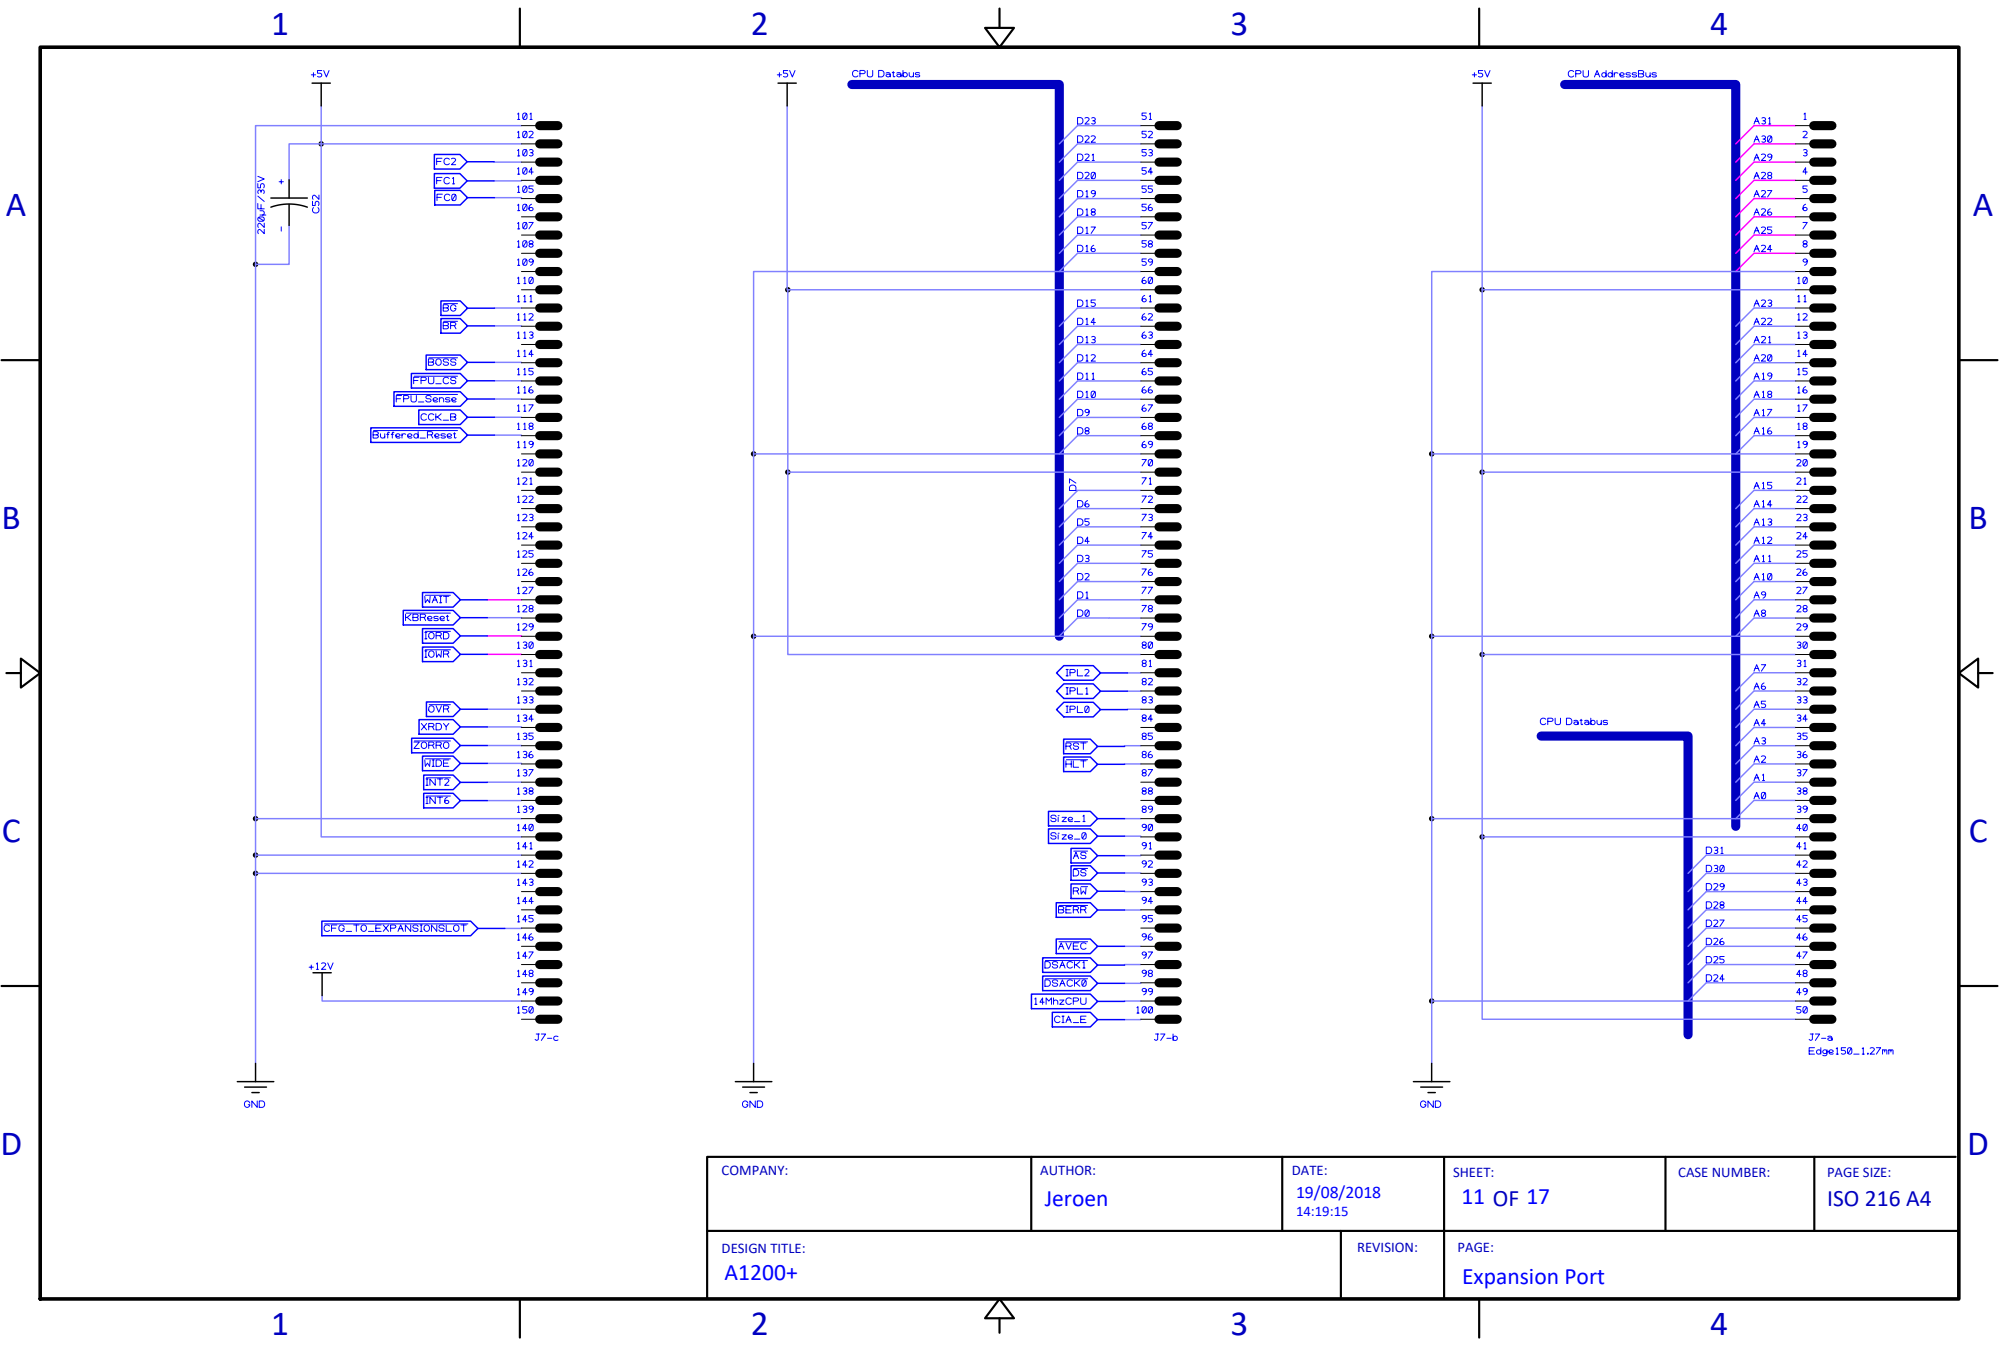
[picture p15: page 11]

A

1 | 2 | 3 | 4

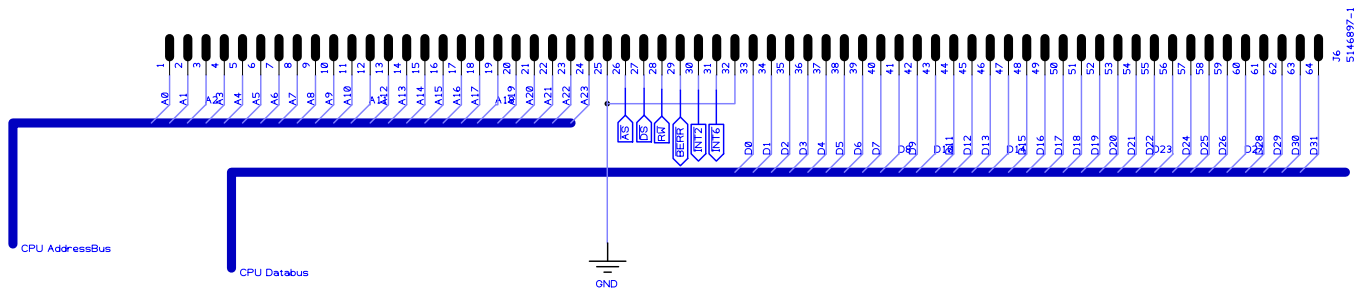
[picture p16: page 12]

# ABCD

# ABCD

Chipset RamAddressBus; DRA0 DRA1 DRA2 DRA3 DRA4 DRA5 DRA6 DRA7 DRA8 DRA9; MOSI; CLK; MISO; MISO GND; GND; J4 TerribleFireSPI; COMPANY:; AUTHOR:; DATE:; SHEET:; CASE NUMBER:; PAGE SIZE:; Jeroen; ISO 216 A4; CPU Board 2; __RAS__ __CAS__ __DWE__; Alice_BLS; Alice_RAMEN; 28Mhz 14MhzCPU; __INT2__ __INT3__ __INT6__; ALice_DBR; Alice_REGEN; Alice_DMAL; __ODD_CIA__; __EVEN_CIA__; CIA_E; __ROMOE__ __ROMCS__; __WIDE__; __SD_ACT__; CCK_B; Reserved for future use

# ABCD

# ABCD

Chipset Databus; DRD0 DRD1 DRD2 DRD3 DRD4 DRD5 DRD6 DRD7 DRD8 DRD9 DRD10 DRD11 DRD12 DRD13 DRD14 DRD15 DRD16 DRD17 DRD18 DRD19 DRD20 DRD21 DRD22 DRD23 DRD24 DRD25 DRD26 DRD27 DRD28 DRD29 DRD30 DRD31; COMPANY:; AUTHOR:; DATE:; SHEET:; CASE NUMBER:; PAGE SIZE:; Jeroen; ISO 216 A4; CPU Board 1; __AS__ __AVEC__ __BERR__; GND; __ZORRO__ __BR__ __DS__ __DSACK0__ __DSACK1__ FC0 FC1 FC2 __HLT__ IPL0 IPL1 IPL2; __LISA_CAS__; __RST__ R__W__ Size_0 Size_1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

A

B


U1-b

A


A20
A19

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

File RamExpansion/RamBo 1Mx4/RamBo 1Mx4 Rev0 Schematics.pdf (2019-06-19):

A

1 | 2 | 3 | 4

Chipset Databus; DRD0; DRD1; DRD2; DRD3; DRD4; DRD5; DRD6; DRD7; DRD8; DRD9; DRD10; DRD11; DRD12; DRD13; DRD14; DRD15; DRD16; DRD17; DRD18; DRD19; DRD20; DRD21; DRD22; DRD23; DRD24; DRD25; DRD26; DRD27; DRD28; DRD29; DRD30; DRD31; Chipset RamAddressBus; DRA9; DRA8; DRA7; DRA6; DRA5; DRA4; DRA3; DRA2; DRA1; DRA0; COMPANY:; DESIGN TITLE:; AUTHOR:; REVISION:; PAGE:; DATE:; SHEET:; CASE NUMBER:; PAGE SIZE:; jeroenvandezande; ISO 216 A4; Connections; GND; __RAS__; __RAS0__; __RAS1__; __CAS__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

# ABCD

1


# ABCD

1


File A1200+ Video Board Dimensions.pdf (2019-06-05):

# Cutout for keyboard connector

99.18mm

TOP SIDE; A1200+ Video Board

Connecter A and B are on the bottom side

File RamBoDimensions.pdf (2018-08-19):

45.65mm

67.61mm

PIN 1; TOP SIDE; Note:

Connectors are on Bottom Side

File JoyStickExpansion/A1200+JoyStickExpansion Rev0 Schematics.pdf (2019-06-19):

A

A


A

A


A

A


# ABCD

1


A

A


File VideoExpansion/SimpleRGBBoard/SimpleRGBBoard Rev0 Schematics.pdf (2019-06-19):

A

1 | 2 | 3 | 4


A

1 | 2 | 3 | 4


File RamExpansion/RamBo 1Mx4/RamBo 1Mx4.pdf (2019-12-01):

A

1 | 2 | 3 | 4


# ABCD

1


# ABCD

1


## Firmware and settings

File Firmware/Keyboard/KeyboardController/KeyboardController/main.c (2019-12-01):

#include <atmel_start.h>
#include <util/delay.h>
#include <port.h>
#include <key_scan.h>
#include <amigakb.h>


int main(void)
{
	/* Initializes MCU, drivers and middleware */
	atmel_start_init();
	_delay_ms(100);

	//boot from DF0:
	__BootFromDF0___set_level(true);
	//boot from DF1:
	//__BootFromDF0___set_level(false);

	//keep keyboard reset line low for another 400ms
	CapsLockLed_set_level(false);
	KB_RESET_set_level(false);
	_delay_ms(800);
	
	keyscan_init();
	amikb_init();

	KB_RESET_set_level(true); //release keyboard reset
	CapsLockLed_set_level(true);
	
	bool capslockState = false;
	
	while (1)
	{
		uint8_t curkey = scankeys();
		if (curkey == 0x62)
		{
			continue;
		}
		if (curkey == (0x62 | 0x80))
		{
			capslockState = !capslockState;
			CapsLockLed_set_level(!capslockState);
		}
		
		if(getResetState())
		{
			//CapsLockLed_set_level(false);
			KB_RESET_set_level(false);
			CapsLockLed_set_level(false);
			_delay_ms(1000);
			CapsLockLed_set_level(true);
		}
		else
		{
			KB_RESET_set_level(true); //release keyboard reset
			//CapsLockLed_set_level(true);
		}
		amikb_sendkey(curkey);
	}
}

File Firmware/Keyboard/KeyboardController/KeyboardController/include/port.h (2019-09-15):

/**
 * \file
 *
 * \brief Tinymega Port related support
 *
 (c) 2018 Microchip Technology Inc. and its subsidiaries.

    Subject to your compliance with these terms,you may use this software and
    any derivatives exclusively with Microchip products.It is your responsibility
    to comply with third party license terms applicable to your use of third party
    software (including open source software) that may accompany Microchip software.

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
    IN NO EVENT WILL MICROCHIP BE LIABLE FOR ANY INDIRECT, SPECIAL, PUNITIVE,
    INCIDENTAL OR CONSEQUENTIAL LOSS, DAMAGE, COST OR EXPENSE OF ANY KIND
    WHATSOEVER RELATED TO THE SOFTWARE, HOWEVER CAUSED, EVEN IF MICROCHIP HAS
    BEEN ADVISED OF THE POSSIBILITY OR THE DAMAGES ARE FORESEEABLE. TO THE
    FULLEST EXTENT ALLOWED BY LAW, MICROCHIP'S TOTAL LIABILITY ON ALL CLAIMS IN
    ANY WAY RELATED TO THIS SOFTWARE WILL NOT EXCEED THE AMOUNT OF FEES, IF ANY,
    THAT YOU HAVE PAID DIRECTLY TO MICROCHIP FOR THIS SOFTWARE.
 *
 */

#ifndef PORT_INCLUDED
#define PORT_INCLUDED

#ifdef __cplusplus
extern "C" {
#endif

#include <compiler.h>
#include <stdint.h>
#include <stdbool.h>
#include <compiler.h>

enum port_pull_mode {
	PORT_PULL_OFF,
	PORT_PULL_UP,
};

enum port_dir {
	PORT_DIR_IN,
	PORT_DIR_OUT,
	PORT_DIR_OFF,
};

/**
 * \brief Set PORTA pin pull mode
 *
 * Configure pin to pull up, down or disable pull mode, supported pull
 * modes are defined by device used
 *
 * \param[in] pin       The pin number in PORTA
 * \param[in] pull_mode Pin pull mode
 */
static inline void PORTA_set_pin_pull_mode(const uint8_t pin, const enum port_pull_mode pull_mode)
{

	if (pull_mode == PORT_PULL_UP) {

		DDRA &= ~(1 << pin);

		PORTA |= 1 << pin;
	} else if (pull_mode == PORT_PULL_OFF) {

		PORTA &= ~(1 << pin);
	}
}

/**
 * \brief Set PORTA data direction
 *
 * Select if the port pins selected by mask data direction is input, output
 * or disabled.
 *
 * \param[in] mask      Bit mask where 1 means apply direction setting to the
 *                      corresponding pin
 * \param[in] direction PORT_DIR_IN  = Data direction in
 *                      PORT_DIR_OUT = Data direction out
 *                      PORT_DIR_OFF = Disables the pin
 *                      (low power state)
 */
static inline void PORTA_set_port_dir(const uint8_t mask, const enum port_dir direction)
{
	switch (direction) {
	case PORT_DIR_IN:
		DDRA &= ~mask;
		break;
	case PORT_DIR_OUT:
		DDRA |= mask;
		break;
	case PORT_DIR_OFF:
		DDRA &= ~mask;

		PORTA |= mask;
		break;
	default:
		break;
	}
}

/**
 * \brief Set PORTA single pin data direction
 *
 * Select if the pin data direction is input, output or disabled.
 * If disabled state is not possible, this function throws an assert.
 *
 * \param[in] pin       The pin number within PORTA (0..7)
 * \param[in] direction PORT_DIR_IN  = Data direction in
 *                      PORT_DIR_OUT = Data direction out
 *                      PORT_DIR_OFF = Disables the pin
 *                      (low power state)
 */
static inline void PORTA_set_pin_dir(const uint8_t pin, const enum port_dir direction)
{
	switch (direction) {
	case PORT_DIR_IN:
		DDRA &= ~(1 << pin);
		break;
	case PORT_DIR_OUT:
		DDRA |= 1 << pin;
		break;
	case PORT_DIR_OFF:
		DDRA &= ~(1 << pin);

		PORTA |= 1 << pin;
		break;
	default:
		break;
	}
}

/**
 * \brief Set PORTA level
 *
 * Sets output level on the pins defined by the bit mask
 *
 * \param[in] mask  Bit mask where 1 means apply port level to the corresponding
 *                  pin
 * \param[in] level true  = Pin levels set to "high" state
 *                  false = Pin levels set to "low" state
 */
static inline void PORTA_set_port_level(const uint8_t mask, const bool level)
{
	if (level) {
		PORTA |= mask;
	} else {
		PORTA &= ~mask;
	}
}

/**
 * \brief Set PORTA level
 *
 * Sets output level on a pin
 *
 * \param[in] pin       The pin number for device
 * \param[in] level true  = Pin level set to "high" state
 *                  false = Pin level set to "low" state
 */
static inline void PORTA_set_pin_level(const uint8_t pin, const bool level)
{
	if (level) {
		PORTA |= 1 << pin;
	} else {
		PORTA &= ~(1 << pin);
	}
}

/**
 * \brief Toggle out level on pins
 *
 * Toggle the pin levels on pins defined by bit mask
 *
 * \param[in] port  Ports are grouped into groups of maximum 32 pins,
 *                  PORT_PORTA = group 0, PORT_PORTB = group 1, etc
 * \param[in] mask  Bit mask where 1 means toggle pin level to the corresponding
 *                  pin
 */
static inline void PORTA_toggle_port_level(const uint8_t mask)
{
	PINA = mask;
}

/**
 * \brief Toggle output level on pin
 *
 * Toggle the pin levels on pin
 *
 * \param[in] pin       The pin number for device
 */
static inline void PORTA_toggle_pin_level(const uint8_t pin)
{
	PINA = 1 << pin;
}

/**
 * \brief Get input level on pins
 *
 * Read the input level on pins connected to a port
 *
 * \param[in] port  Ports are grouped into groups of maximum 32 pins,
 *                  PORT_PORTA = group 0, PORT_PORTB = group 1, etc
 */
static inline uint8_t PORTA_get_port_level(volatile uint8_t *port)
{
	return PINA;
}

/**
 * \brief Get level on pin
 *
 * Reads the level on a pin connected to a port
 *
 * \param[in] pin       The pin number for device
 */
static inline bool PORTA_get_pin_level(const uint8_t pin)
{
	return PINA & (1 << pin);
}

/**
 * \brief Write value to PORTA
 *
 * Write directly to the entire port register.
 *
 * \param[in] value   Value to write
 */
static inline void PORTA_write_port(const uint8_t value)
{
	PORTA = value;
}

/**
 * \brief Set PORTB pin pull mode
 *
 * Configure pin to pull up, down or disable pull mode, supported pull
 * modes are defined by device used
 *
 * \param[in] pin       The pin number in PORTB
 * \param[in] pull_mode Pin pull mode
 */
static inline void PORTB_set_pin_pull_mode(const uint8_t pin, const enum port_pull_mode pull_mode)
{

	if (pull_mode == PORT_PULL_UP) {

		DDRB &= ~(1 << pin);

		PORTB |= 1 << pin;
	} else if (pull_mode == PORT_PULL_OFF) {

		PORTB &= ~(1 << pin);
	}
}

/**
 * \brief Set PORTB data direction
 *
 * Select if the port pins selected by mask data direction is input, output
 * or disabled.
 *
 * \param[in] mask      Bit mask where 1 means apply direction setting to the
 *                      corresponding pin
 * \param[in] direction PORT_DIR_IN  = Data direction in
 *                      PORT_DIR_OUT = Data direction out
 *                      PORT_DIR_OFF = Disables the pin
 *                      (low power state)
 */
static inline void PORTB_set_port_dir(const uint8_t mask, const enum port_dir direction)
{
	switch (direction) {
	case PORT_DIR_IN:
		DDRB &= ~mask;
		break;
	case PORT_DIR_OUT:
		DDRB |= mask;
		break;
	case PORT_DIR_OFF:
		DDRB &= ~mask;

		PORTB |= mask;
		break;
	default:
		break;
	}
}
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

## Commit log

2018-07-03 started on mounting holes
2018-07-15 Added CPU Board Connector pinout
    [A1200+.sch, CPU Board Connections.xlsx]
2018-08-04 More work
    [A1200+.sch, CPU Board Connections.xlsx]
2018-08-11 CPU connectors relocated. more routing
    [A1200+.sch]
2018-08-12 finished RS-232 and floppy
    [A1200+.sch]
2018-08-18 More routing
    [A1200+.sch]
2018-08-18 ready for final routing
    [A1200+.sch]
2018-08-18 Rev0 of PCB uploaded
2018-08-19 Updated RamBo Connections and also added RamBo Layout
    [A1200+.sch, CPU Board Connections.xlsx, RamBo Connections.xlsx]
2018-08-20 revised Gerber files
2018-08-31 small fixes
    [A1200+.sch]
2018-09-19 Added schematics PDF
2018-11-02 Rev1 to manufacturer
    [A1200+.sch]
2019-03-09 Fixed issues with misaligned DRD bus on Alice.
    [A1200+.sch]
2019-06-03 Finished Rev2
    [A1200+.sch]
2019-06-05 Fixed issue where a 12V line was too close to the edge connector.
2019-06-05 Added PDF with the video board dimensions
2019-06-05 Started on Simple RGB Video board
    [A1200+SimpleRGBBoard.sch]
2019-06-06 more work on video board
    [A1200+SimpleRGBBoard.sch]
2019-06-09 Added a new RAM board for 1Mx4 DRams
    [A1200+SimpleRGBBoard.sch, RamBo 1Mx4.sch]
2019-06-09 Started on Joystick expansion board
    [A1200+JoyStickExpansion.sch]
2019-06-11 finished Rev0 of the Joystick expansion board
    [A1200+JoyStickExpansion.sch]
2019-06-19 Added BOM and schematics of the simple RGB Board
    [A1200+.sch, A1200+JoyStickExpansion.sch]
2019-06-19 Added the joystick expansion BOM and schematics
2019-06-19 Added schematics and BOM
    [RamBo 1Mx4.sch]
2019-07-11 More work for Rev3
    [A1200+.sch]
2019-08-08 More work on Rev3
    [A1200+.sch, A1200+JoyStickExpansion.sch, RamBo 256Kx16.sch]
2019-08-15 Updated various PCBs for Amiga34
    [A1200+JoyStickExpansion.sch, A1200+SimpleRGBBoard.sch, RamBo 1Mx4.sch]
2019-08-21 Last commit before move to Git
    [RamBo 1Mx4.sch, RamboDebug.sch]
2019-08-26 Added missing ZZ1200 project
    [RamBo 1Mx4.sch, ZZ1200.sch]
2019-09-15 started on keyboard controller firmware. + rev5 of A1200+ pcb
2019-11-30 Added schematics of older revisions
2019-12-01 cleaning up in process of restarting from rev3
    [A1200+JoyStickExpansion.sch, A1200+SimpleRGBBoard.sch]
2019-12-01 (no branch): Auto stash before checking out "HEAD"
    [A1200+ (BOM 2 Csv Sorted).csv, A1200+ (BOM Csv).csv, A1200+ (Pick And Place Csv).csv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]
2019-12-01 re-starting from rev3 pcb
2019-12-15 Finished routing of Rev6 PCB
2020-09-20 More work on rev7
    [ZZ1200.sch]
